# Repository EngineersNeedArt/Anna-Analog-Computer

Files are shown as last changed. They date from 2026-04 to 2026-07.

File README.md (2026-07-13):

# “Anna” Analog Computer

***Anna*** is an ecosystem of analog computing modules. The modules (each about the size of a matchbook) make use of a hobbyist breadboard and USB power that combine to make something like an analog computer trainer.

<p align="center">
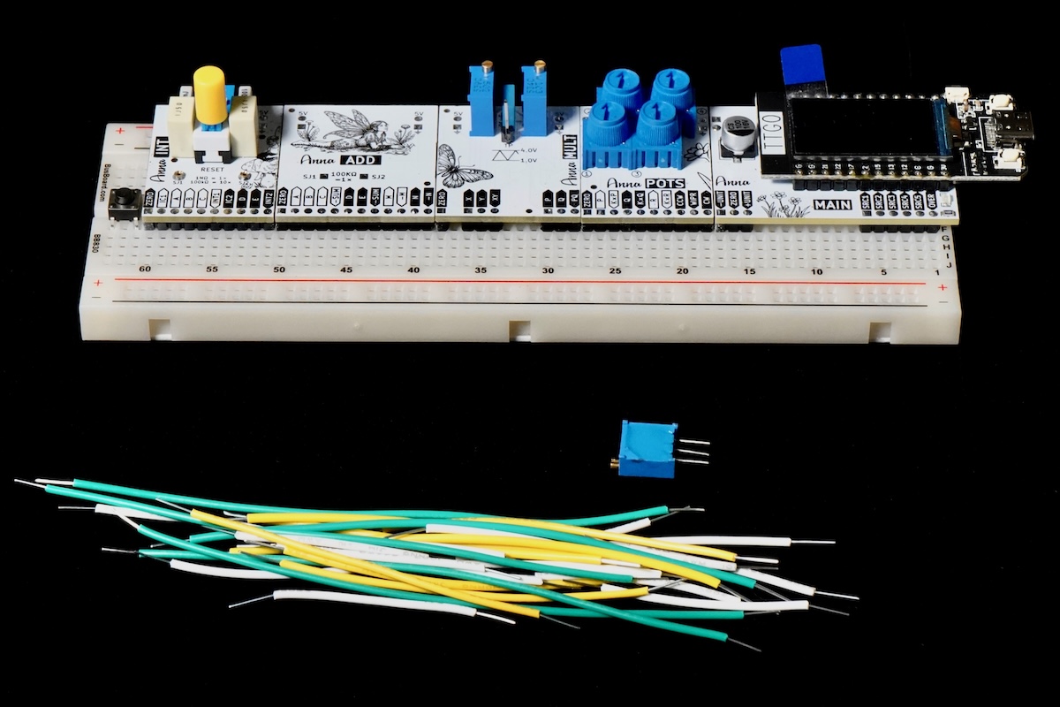
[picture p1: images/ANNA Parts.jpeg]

</p>

### Breadboard

An electronics breadboard is an integral part of ***Anna***. The breadboard allows ***Anna*** to be easily modular, expandable. It provides a power bus (the top two power rails of the breadboard) and it is acts as the “patch bay” that allows you to connect inputs and outputs between the various analog operators.

### Power

The modules comprising ***Anna*** all run on (nominally 5V) USB power. All modules but **MAIN** assume that the top two power rails of the breadboard supply this USB power. The top rail (row) of the breadboard is assumed to be +5V and the rail (row) below is assumed to be ground (GND).

While these power rails operate the electronics for each module, these rails are not to be used for the analog *programming*. There are instead three reference voltages used in the analog computing domain. These are:
- **+UNIT**, nominally 4.00V. Representing the largest machine value (+1 if you like).
- **ZERO**, nominally 2.50V. Representing the machine value zero (0).
- **-UNIT**, nominally 1.00V. Representing the smallest machine value (-1 if you like).
Needless to say, this makes the voltage window for representing values in ***Anna*** a very narrow 3 volts. Perhaps this is a good time to remind you that it is intended to be a *hobbyist* analog computer. 

## **The Modules**

### MAIN Module

<p align="center">
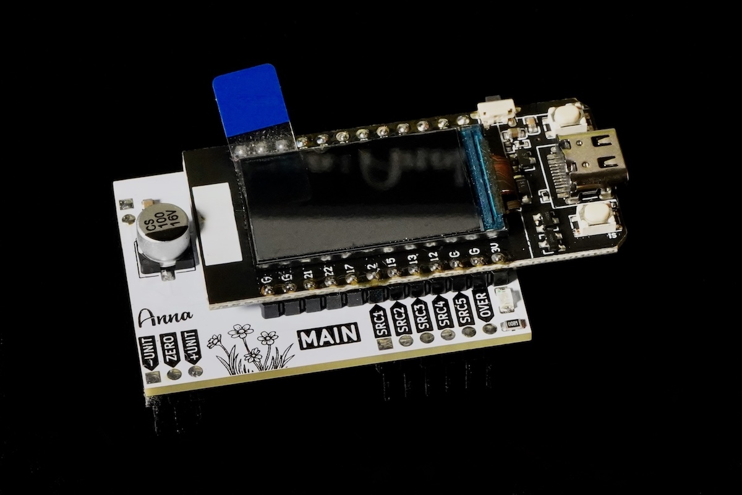
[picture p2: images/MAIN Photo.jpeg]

</p>

The **MAIN** module is required for any ***Anna*** configuration as it provides USB power to the top two rails of the breadboard. These USB power rails are what all other ***Anna*** modules depend upon to operate.
- Provides USB power to the top two power rails on the breadboard—powering all other ***Anna*** modules.
- Provides the reference voltages for **+UNIT**, **ZERO** and **-UNIT**. These are the operating voltages of the analog computer programs.
- Inputs for up to five source voltages for display on the color LCD.
- Numerous metering modes (can be cycled through using the top button on the module).
- Overload LED (and output pin) indicate when a source voltage is out of range (higher than **+UNIT** or lower than **-UNIT**).

More (esoteric) details are available in the **README** that with the **MAIN** subfolder in this repository.

### POTS Module

<p align="center">
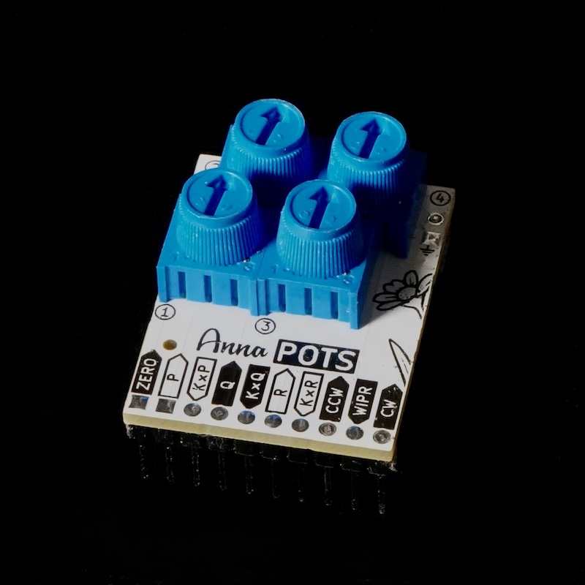
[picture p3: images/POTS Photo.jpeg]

</p>

The **POTS** module, as with the remaining modules described, is to be inserted into a breadboard such that its power pins engage in the top two power rails (top-most row: **USB 5V**, the row just below: **GND**). As described above, the **USB** power is provided by the **MAIN** board.

The **POTS** has four potentiometers—three of those are wired internally to behave as “coefficient multipliers” (in analog computer parlance). What this means, electrically, is that the low-side of the potentiometer is tied to a *machine zero* reference supplies by **MAIN**, while the user is expected to connect their input signal to the pin tied to the potʼs high-side. With the potʼs wiper connected to the output pin, the pot acts as a voltage divider—effectively attenuating the incoming voltage.

A practical use case for a coefficient multiplier is to attenuate a signal that is being used as feedback.

The 4th potentiometer on the **POTS** module is not tied to a zero-reference—the high-side of the pot is another input pin. The input pins are labeled **CCW** and **CW** referring to the rotation of the pot they correspond to. Connecting **CCW** to a **ZERO** reference makes this 4th pot behave like the other three—like a coefficient multiplier.

Like all of the modules (except for **MAIN**), **POTS** requires a **ZERO** voltage reference for the three coefficient multipliers to work correctly. The modules use op-amps employing a *virtual ground*. As indicated earlier, rather than the analog *voltages* swinging positive and negative to indicate positive and negative *values*, “zero” for ***Anna*** is 2.50V— positive values are from 2.50V to 4.00V, negative values from 2.50V down to 1.00V. So that all the modules are on the same page, they require the virtual ground connected to them from the **MAIN** module (a pin labeled **ZERO**).

(Strictly speaking, if you are using only the fourth potentiometer, you can leave off the **ZERO** reference input.)

All four pots buffer their output (using op-amps as voltage followers).

### ADD Module

<p align="center">
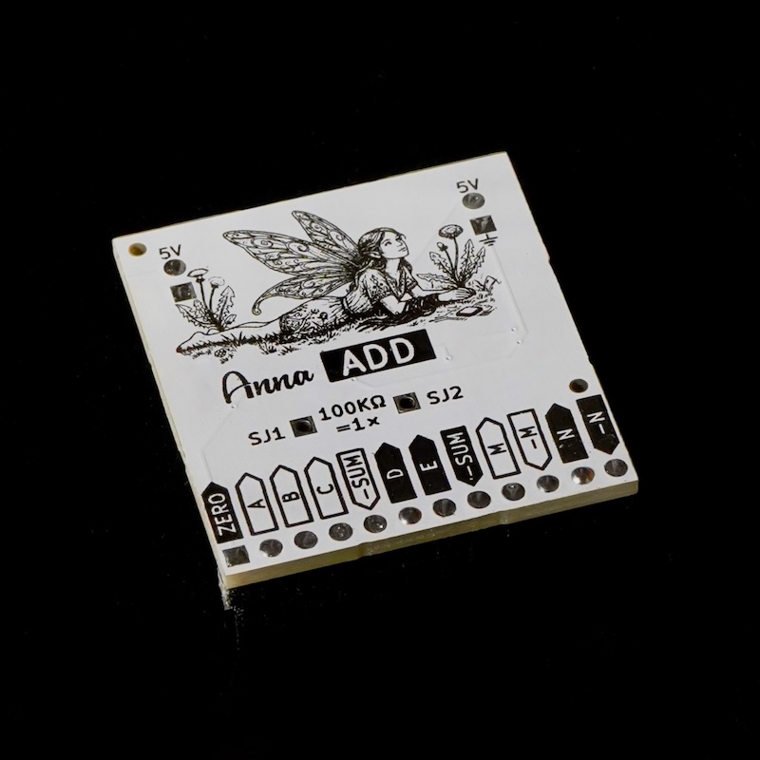
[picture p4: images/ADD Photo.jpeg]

</p>

The **ADD** module also requires **USB** power and also a **ZERO** reference voltage.

The **ADD** module has a pair of addition operators. (Or *summers*? I don't know: a “summer” is a season and an “adder” is a snake—they're both poor words). These operators take 2 or more inputs (values/voltages) and output the negative sum of those inputs.

#### Overload 

Analog computers programs have to be careful to avoid a condition referred to as **overloading**. The addition operation makes a good case for the problem. Given the voltage limitation of ***Anna*** (1V to 4V, i.e. *machine -1* to *machine +1*) what do we expect if we try to add 4V and 4V (*machine +1* plus *machine +1*)? To dive into the technical, the underlying op-amps that comprise the analog circuitry physically cannot exceed their own power rails—which we have mentioned are **5V USB** and **GND**. So a sum of 8V is already out of the question.

Instead, this condition is considered an error, called **overload**. The "programmer" must re-evaluate the program they have patched together—re-implement it to avoid overload. This might involve artificially scaling down part of an equation and then later "de-scaling" to counter.

There is no on-board overload warning on the **ADD** module. Wiring the output of any add operator to one of the voltage source inputs of **MAIN** though will catch any overloads (**MAIN** detects over/undervolts at all its inputs).

Also, going too negative (below 1V in the case of ***Anna***) is oddly also called an *overload*.

#### Inversion

You may notice that the add operators return the *inverted* sum of the inputs. That is, if you input the values for 0.2 and 0.4, the sum operator will return not 0.6 but -0.6. There is an underlying (op-amp related) reason for this. When the result of adding is needed to act as negative feedback in an equation you are modeling, this inversion is a happy accident. At times though when you need the non-inverted sum, you will have to wire the output of a summer to an inverter operator.

Any add operator with a single input will return that input value inverted as output. But since inverting is a common operation, the **ADD** module contains a pair of dedicated inverter operators. (A dedicated inverter of course needs less pins and so conserves breadboard real-estate).

### MULT Module

<p align="center">
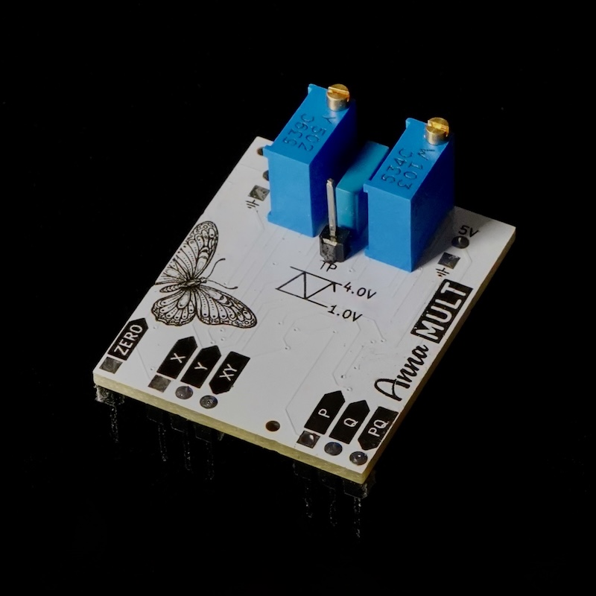
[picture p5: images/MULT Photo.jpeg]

</p>

The **MULT** module has a pair of multipliers. It performs multiplication using a PWM circuit (described in more detail in the **MULT** ReadMe.md). It requires **USB** power and a **ZERO** reference voltage.

The multiplier and multiplicand are assumed to be within *machine range* and are treated as values between 1.0 and -1.0. As such, the product will also always be within *machine range* (between 1.0 and -1.0). Consequently, the operator should not overload. (If the product ever overloads it is from an input that was already overloaded.)

A test point and two trim pots are there to allow the multiplier to be calibrated. (This requires an oscilloscope in order to adjust a triangle wave to run between 1.00 and 4.00 Volts.) After calibrating a **MULT** module, I measured it with 49 sample voltages (combinations of 7 voltages for **X** and 7 for **Y**) and measured the product. Plotting the results vs. the expected result I submitted the data to an LLM and was told the overall accuracy to be about 2.3% RMS full scale (I am lazy beyond some threshold). In general, expect some error from the **MULT** module.

### INT Module

<p align="center">
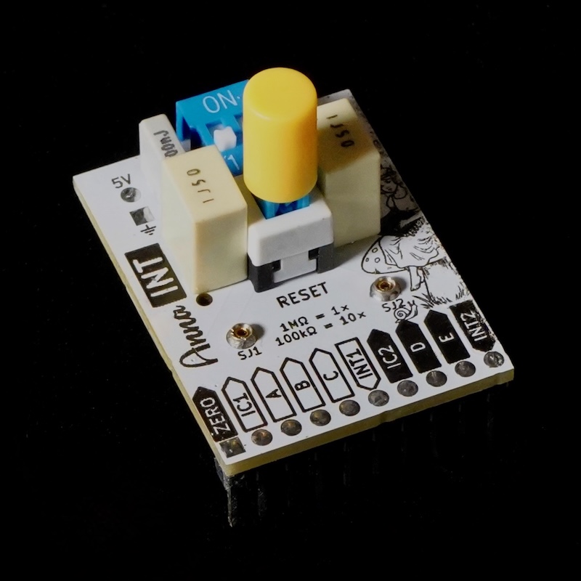
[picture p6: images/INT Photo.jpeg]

</p>

The **INT** module may be the most important one. I have read that integration was in fact the reason for early analog computing at all.

**INT** combines a pair of integrators in a single module. A single **Reset** button, when held for a short period, sets both integrators to their initial conditions (initial voltages). The “IC” of each integrator is established from the user having connected a voltage to its **IC** pin.

Integrators output a voltage—initially they are expected to be Reset and so output their IC voltage. Inputs to each integrator though can cause the output voltage of the integrator to rise or fall—the applied voltage or value is being integrated with respect to time.

Like the **ADD** module, the integrators on the **INT** module are also inverting. In practice this means that if you supply a **positive** *machine value* to an integrator, the value it outputs will get **smaller**, not larger. The reverse is the case when a **negative** machine value is applied.

If *machine zero* (**ZERO**) is applied as in input, the output of an integrator does not change.

Integrators integrate with respect to time and there is a switch on **INT** that can toggle between a *slow* integration time constant and a *fast* one. In practice, most simulations (programs), might prefer the faster integration—such as a program that models the bounce of a mass on a spring. Another program, like a game simulating a spacecraft landing on the Moon, might want to be slowed down in order to be more easy to play.

## **Future Modules**

There are some “missing modules” that will perhaps show up over time.

### Log and Anti-log Modules

Searching through older analog computer sources, you can find circuits that take a voltage as input and then output the natural **log** of that voltage. A diode (or more typically, a transistor) is employed in the *feedback loop* of an op-amp to achieve this.

Further, a diode (transistor) employed in *series* with the input to an op-amp will give you the **anti-log** from an input voltage.

*(It might be noted that the accuracy of both circuits is (apparently) encumbered by their sensitivity to temperature.)*

If a value is first passed to the **log** circuit, the result can be divided by two with a **coefficient multiplier**—the **anti-log** of this then gives you the square root of the original value.

Or, the **log** of two values can be added with an **adder** and the **anti-log** of the sum is the equivalent of the product of the original values. (Another method of multiplication.)

### Comparator Module

For some simulations a kind of *binary switch* might be desirable. For example, a bouncing ball simulation needs to know when the ball has fallen to some position where it has encountered the floor and should reverse its velocity (it should bounce). A **comparator** module would make use of an op-amp to detect when the input has crossed some threshold and then switch its output.

### Sweep Module

Some simulations might benefit by having an input that sweeps a range of values. A circuit that outputs a triangle wave would achieve this. Having a means to change the speed (period) of the sweep would be important.

### Trigonometry Module

Sine and cosine are useful operations to include. There are no simple electrical circuits that naturally give rise to these trigonometric functions. There is a method using diodes and resistors to *shape* a function from a given input. Enough diode stages in a kind of ladder configuration with precise resistor values can output a voltage that approximate, for example, the sine of the input voltage.

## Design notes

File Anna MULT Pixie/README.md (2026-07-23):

# MULT Module

The **MULT** module has two multiplier operators. Both take a pair of values assumed to be within *machine range* (between 1.0V and 4.0V). Each outputs the product of the two inputs. The outputs (products) from the **MULT** module are not inverted as they are for the **INT** and **ADD** module. This is because the **MULT** module works very differently (as is discussed below).

### ZERO

Before going further though, like the other operator modules, *machine zero* (**ZERO**, 2.5V) is a required input. The usual way to do this is to connect a wire from the **MAIN** module's **ZERO** voltage output.

### Multiplication Operation

As stated, the two values to be multiplied are assumed to be between *-UNIT* and *+UNIT*. The multiplier operators treat this range of input values as though they represent -1.0 to +1.0. With -1.0 (*-UNIT*) being the smallest value and +1.0 (*+UNIT*) the largest value to be multiplied, it should be clear that, mathematically, the product too will always be within this range. For this reason, the **MULT** module should not ever be a source of *overflow*. (The product should only overflow if one of the multiplicands was already overflowing.)

### Circuit Operation

As stated, multiplication is done in a way very different from the op-amp based modules. Describing how it works is simplified if it is broken down in steps.

<div align="center">
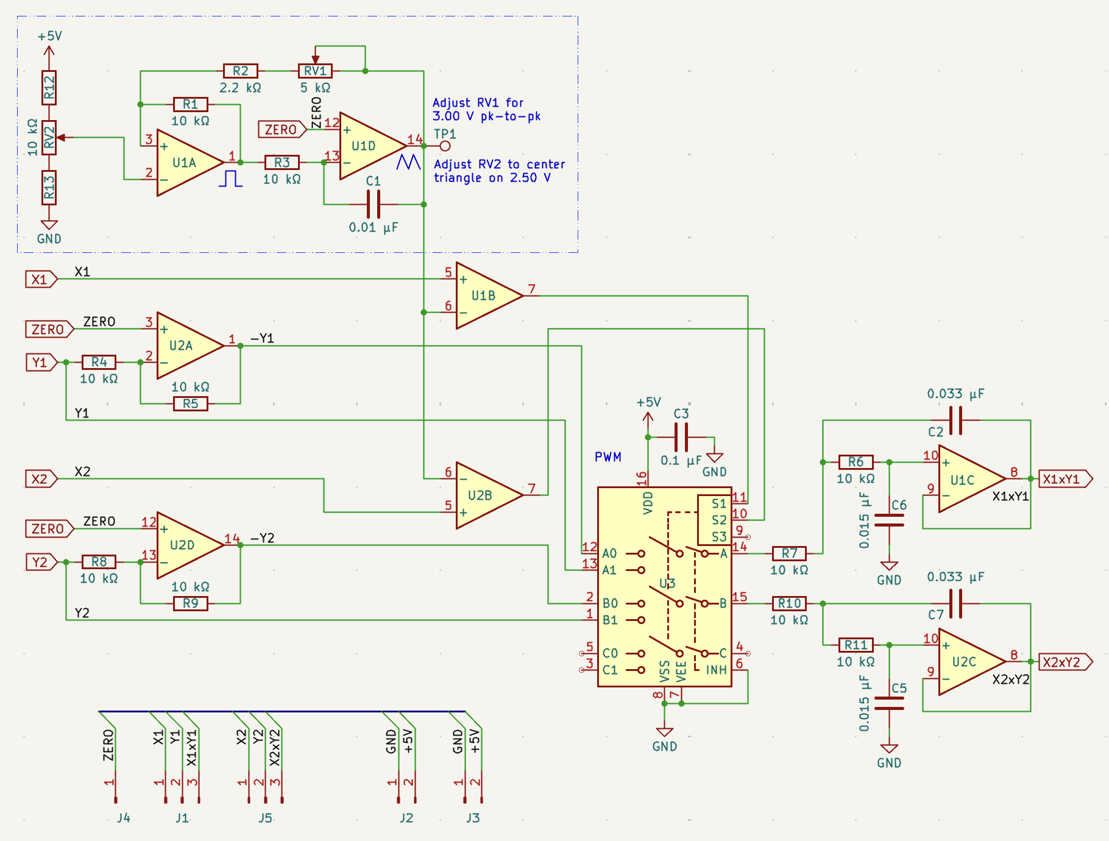
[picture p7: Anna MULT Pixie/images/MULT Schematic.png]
MULT Schematic
  
</div>

### Triangle Wave

Top-most in the schematic (above) is a circuit that outputs a triangle wave. It consists of a pair of op-amps: the first one acting as an oscillator to create an intermediary square wave, the second op-amp is wired as an integrator such that the incoming square wave causes the final triangular output.

Two trim pots are incorporated in order to adjust the triangle wave such that it peaks at 4.0V (*+UNIT*) and at it's lowest, base voltage, it is at 1.0V (-UNIT).

The purpose of the triangle wave (that oscillates at a frequency of about 4 kHz, FWIW) will be clear below.

### Comparators

Just below the triangle wave circuit (see schematic above again) is one of the multiplicand inputs labeled **X1**. It is connected to the non-inverting input of an op-amp (*U1B*). The inverting input of that op-amp if the triangle wave we described. With op-amp configured as a comparator, the output is going to be high when the non-inverting input is a greater voltage than the inverting input. For our purposes, it means that the op-amp output is high when the multiplicand (*X1*) is greater than the value of the triangle wave.

Let's stop and think about what that means. If **X1** is *machine zero* (recall, 2.5V) and the triangle wave is ramping up and down symmetrically between 1.0V (*-UNIT*) and 4.0V (*+UNIT*), then it should be the case that the output from the comparator is split 50/50 between being high and being low.

If instead **X1** is greater than *machine zero* (greater than 2.5V) then the output from **U1B** should be higher more than 50% of the time. If this sounds to you like **X1** is controlling the *duty cycle* of comparator **U1B**, pat yourself on the back.

You should note that an identical circuit to the one just described exists below on the schematic—for **X1** and **U2B**. I will only be describing the one circuit.

### Switching

Following the schematic, the pulse-width modulated (PWM) output from **U1B** goes to the rather large rectangular circuit/chip. This integrated circuit is an analog switch, and **U1B** is connected to drive one of the internal switches (*S1*). This is the "A" switch in the IC and it controls whether **A0** or **A1** are selected for output **A**.

Recall that if **X1** is *machine zero* we expect a 50% duty-cycle. This would mean that **A** would output **A0** half of the time and **A1** the other half of the time. And what then are **A0** and **A1**?

**A1** is simple, it comes directly from **Y1**, our multiplier.

**A0** is a little more complicated, it comes from an op-amp (*U2A*) acting as an inverting op-amp. In fact, **A0** is **Y1** inverted (the negative value). So if **Y1** is *+UNIT*, **U2A** will output *-UNIT*. Another example, if **Y1** is *machine zero*, the inverted value is also *machine zero*.

What does this mean if we are switching between **Y1** and inverted **Y1**? Before we answer that question, let's look at the final stage of the circuit.

### Filtering

The final stage for our multiplier operator that began with is **X1** and **Y1** is the op-amp (*U1C*) that outputs the product (**X1×1**). This final op-amp is configured as an active filter. It *smooths* the output of switch **A** to a voltage (value) that is the kind of average of the output.

Back to our early example, if we are switching between **Y1** and **-Y1** (inverted **Y1**) and spending 50% of the time at each voltage, the *average* value will be *machine zero*. Does that make sense? If **Y1** is *+UNIT* then **-Y1** will be *-UNIT* and, when averaged, will give *machine zero*.

In fact, this is what we expect mathematically: recall that 50% duty cycle was for an **X1** that was *machine zero*—and any number multiplied by zero if of course zero.

So what happens when **X1** is greater than *machine zero*? We said above that the output of our comparator would be high more often than low in that case. This will correspond to **Y1** being switched in more often than the inverted **-Y1**. And this will *average* out to a value closer to **Y1**.

In the extreme case, if **X1** is *+UNIT* (the largest value and treated as though it is numerically 1.0) then the output of the comparator should remain high and the switched output then simply **Y1**. Again, this is expected as 1.0 times any number is that number.

I'll leave it as an exercise for you to understand the operation of the circuit when **X1** is *-UNIT* or when **Y1** is *machine zero*.

## TODO

• An inverted output would be nice: **-X × Y**. This would require additional op-amps.

• There is a cap that is a touch too close to the edge of the PCB.

• Silkscreen show **X × Y** instead of **XY**. (Perhaps **X ⋅ Y**)

• Larger butterfly art.

• Possibly replace trim pots with specific resistor values found to be correct.

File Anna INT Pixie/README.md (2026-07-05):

# INT Module

The **INT** module consists of a pair of integrators. One of the integrators has three inputs and the other has two.

<div align="center">
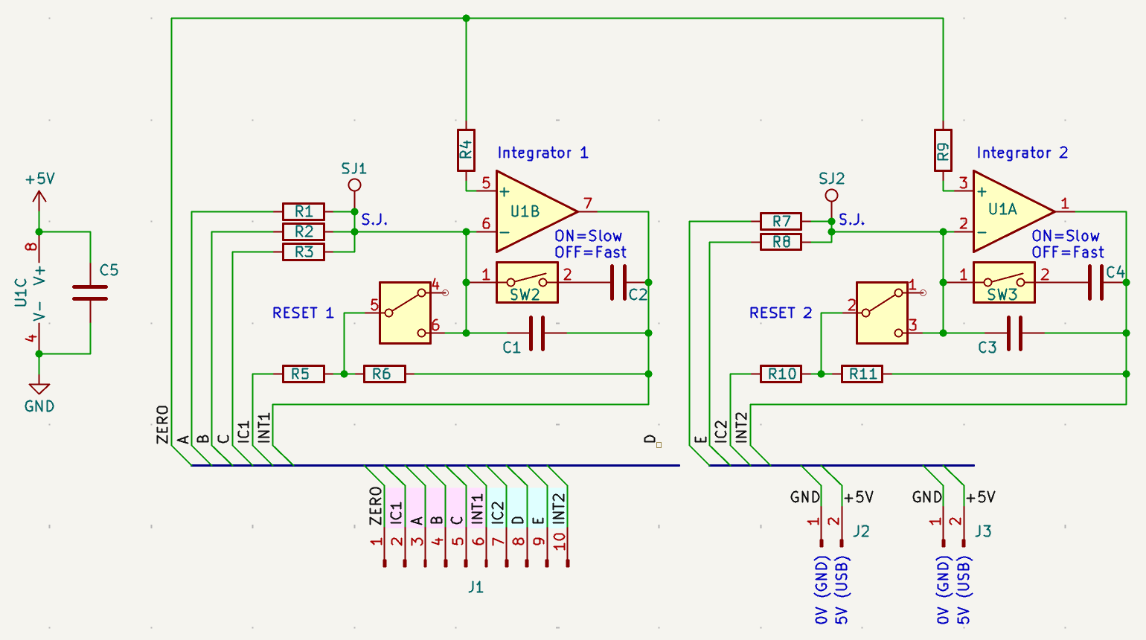
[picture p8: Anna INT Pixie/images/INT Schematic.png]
INT Schematic
  
</div>

## Zero

It will probably come as no surprise that the **INT** module also expects a *machine zero* reference as input. Like the **ADD** module, *machine zero* (ZERO) is used as a *virtual ground* on the non-inverting input of the op-amps.

Like the **ADD** module, this is why the output of the integrator is inverted. Since input values/voltages are connected to the inverting input, they have an inverse effect on the output of the integrator. A positive value (voltage above 2.5V) will in fact cause the integrator output to decrease while a negative value (a voltage below 2.5V) causes the integrator output to become more positive.

## Reset

Each integrator has an *initial condition* (IC) input. This is a value/voltage that the user supplies to be the starting value (output) for each integrator. A single momentary switch, when held down for a short time, resets both integrators to this initial condition.

## Integration Speed

Unlike the other **“Anna”** modules, the integrators have a kind of *speed* associated with them—the speed of integration. The value of the input resistors and the size of the capacitor in the op-amp feedback circuits contribute to determine the speed of integration.

It was found that some simulations, like *Lunar Lander* for example, preferred a slower integration time—to allow the player to react to their descending spacecraft. Other simulations, such as a mass on a spring, felt more realistic with a faster integrator.

To address either scenario, the **INT** module has a separate switch for each integrator that allows for toggling in or out of the op-amp feedback an additional capacitor. With just the one capacitor in the feedback path, an integrator will run faster for simulations like the *spring and mass*. Switching in a second capacitor in parallel slows the integration down by roughly an order of magnitude—making a game like *Lunar Lander* playable.

## Summing Junctions

Like the **ADD** module, the **INT** module also makes accessible the “summing junction” for each integrator. The summing junction is where all the inputs tie together and connect to the inverting input of an op-amp.

If a user wishes for an additional input, a 1 MΩ input resistor can be connected in series with the input and one of the summing junctions on the **INT** module.

Alternatively, if a smaller resistor value is used as an input resistor, such as a 100 kΩ resistor, that input will move the integrator 10x (ten times) as fast. It is possible then to have a much quicker integrator (or much slower) by using input resistors other than 1 MΩ.

## TODO

• Claude suggested adding a "pull to ZERO" resistor on every input. (Perhaps using 10MΩ resistors.)

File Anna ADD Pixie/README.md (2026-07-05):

# ADD Module

Like the other **“Anna”** modules, the **ADD** module is powered by 5V (nominal) USB voltages. Pins along the top edge are placed and spaced to draw USB power from the top two *power rails* of a standard electronics breadboard. The circuitry of the **ADD** module consists of operational amplifiers (op-amps) to perform the adding of voltages—the USB power limits the output of the **ADD** module to within the 0V to 5V range.

Also like the most of the other **“Anna”** modules, the **ADD** module requires a “zero” reference of 2.50V. An input pin in the lower-left corner of the PCB is provided for this reference voltage to be supplied. The 2.50V is supplied to the non-inverting input of the op-amps that perform the operations and therefore acts as a *virtual ground*.

## Overload

Currently there is no **overload** detection on the **ADD** module itself. If the result of operating on an input voltage results in a voltage outside of the range of **“Anna's”** defined machine range of 1.0V and 4.0V, it is simply presented as is. The **MAIN** module has overload detection on all five of its source voltage inputs and is typically where you will detect an overload.

<div align="center">
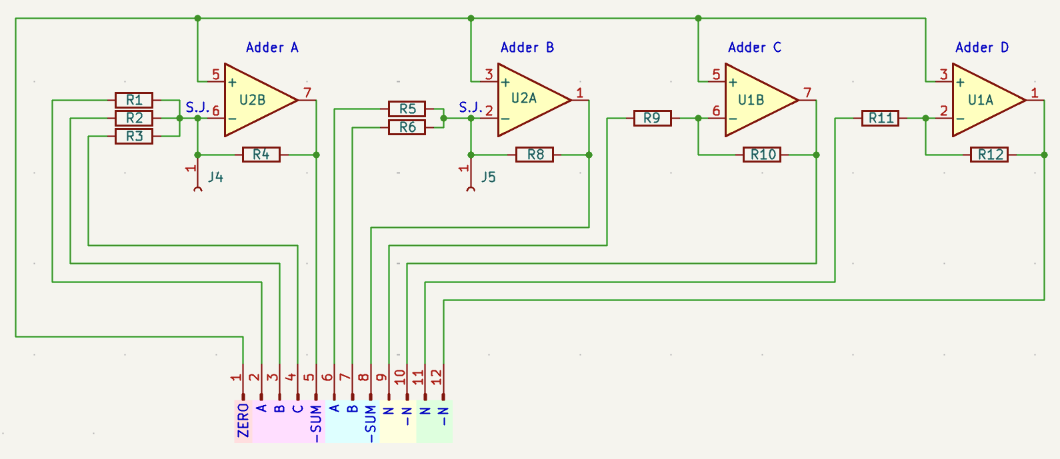
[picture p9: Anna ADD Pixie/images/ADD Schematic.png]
ADD Schematic
  
</div>

## Summing Junction

The schematic (above) shows four op-amps, their non-inverting inputs tied to virtual ground (“zero”, 2.50V). Adder **A** has three inputs and adder **B** has two—these are connected to the inverting inputs of the corresponding op-amps. In both cases, where the inputs tie together (known as the *summing junction*) and test-point is provided such that a user can join additional inputs if desired.

Input resistors on the **ADD** module are 100 kΩ. If similar resistor values are used for additional inputs at the summing junction, the extra inputs will be added normally. However, an input resistor value 10x (ten times) 100 kΩ (1 MΩ) will “weigh” the input by 0.1x (one-tenth). An input resistor that is 0.1x of 100 kΩ (10 kΩ) has the opposite weighting effect—the input is treated as 10x (ten times).

## Inverted Output

By connecting the inputs to be added to the inverting input of the op-amp, the result will also be inverted—the inverted sum of the input voltages. This is why the **ADD** module returns the negative sum (-SUM). I am not expert enough in electronics to understand fully why we use the inverting input for the summing junction.

From an LLM (since this is where it gets fuzzy for me), “The summing junction works because each voltage input behaves independently—seeing only its source voltage across its input resistor, with virtual ground on the other end. That virtual ground exists at the inverting input because the op-ampʼs feedback loop continuously drives it to match the actual ground connected to the non-inverting input. You canʼt simply swap the summing junction to the non-inverting input because virtual ground only exists at the inverting input—without it, the inputs interact with each other and the clean superposition breaks down.”

## Inverters

When analog computing, it turns out that inverting a value is common enough that the **ADD** module dedicates two op-amps just to take an input and return the inverted output. While any **ADD** operator will do the same with a single input, the dedicated inverters save on “breadboard real-estate” (number of pins).

## TODO

• Claude suggested adding a "pull to ZERO" resistor on every input. (1MΩ to 10MΩ)

• S.J. (summing junction) hole is the wrong size.

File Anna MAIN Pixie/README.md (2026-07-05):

# MAIN Module

## Software

**MAIN** features a *daughter board* consisting of an ESP32 Dev Board that includes an LCD display and two soldered-on pushbuttons. Software written for **MAIN** makes use of the display and buttons.

## Metering Modes

The bottom-right button, the one closest to the user, Iʼll call the *mode button*, was chosen to cycle through **MAIN**s various metering modes. The other button, Iʼll call the *options button*, often cycles through various options for the selected metering mode.

### Vertical Meters

<div align="center">
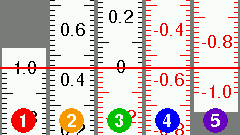
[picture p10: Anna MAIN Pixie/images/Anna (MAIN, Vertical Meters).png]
Vertical Meters screenshot

</div>

The default metering mode consists of five moveable, vertical meters and a fixed red index line. They are labeled 1 through 5 and correspond to the inputs on **MAIN**, **SRC1** through **SRC5**. The *options button* allows you to toggle the number of inputs displayed from the 5 down to just 1. Overload is represented by the labels flashing.

### Sweep Meters

<div align="center">
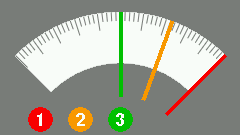
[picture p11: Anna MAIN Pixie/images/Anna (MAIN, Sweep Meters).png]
Sweep Meters screenshot

</div>

Looking like traditional analog panel meters, the magic of digital emulation means that 5 needles can share the same meter. They are labeled 1 through 5, color coded, and correspond to the inputs on **MAIN**, **SRC1** through **SRC5**. The *options button* allows you to toggle the number of inputs displayed from the 5 down to just 1. Overload is represented by the labels flashing.

***(NOTE: in the screenshot only 3 inputs are enabled.)***

### Strip Chart

<div align="center">
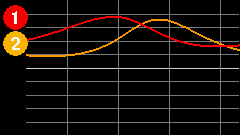
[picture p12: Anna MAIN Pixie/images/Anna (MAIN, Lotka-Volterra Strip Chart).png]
Strip Chart screenshot

</div>

The Strip Chart is a moving metering mode that can display all 5 source inputs with roughly 4 seconds of history visible. The vertical rules that scroll by mark off 1 second intervals. The *options button*  allows you to toggle the number of inputs displayed. *Overload* is represented by the labels flashing.

***(NOTE: in the screenshot only 2 inputs are enabled.)***

### XY Scope

<div align="center">
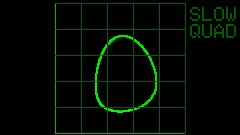
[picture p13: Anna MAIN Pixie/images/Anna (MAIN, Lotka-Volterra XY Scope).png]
XY Scope screenshot

</div>

The XY Scope is patterned after an oscilloscope. It makes use of **SRC1** to control the X-position of a dot and **SRC2** to control the Y-position. The *options button* toggles between displaying the whole *machine value* range to displaying just Quadrant I (the positive *machine values*). The *options button* also toggles between two *fade speeds* for the phosphor trace: slow and fast.

### Spring + Mass

<div align="center">
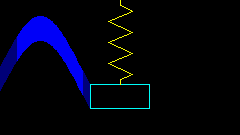
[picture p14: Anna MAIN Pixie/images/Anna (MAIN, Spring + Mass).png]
Spring + Mass screenshot

</div>

Spring + Mass is a special demonstration metering mode. It represents a mass on a spring. The vertical position of the mass is controlled solely by the voltage at **SRC1**. The *options button* does nothing.

The mass leaves a “trail” sort of like the Strip Chart. A color change indicates 1-second intervals.

### Lunar Lander

<div align="center">
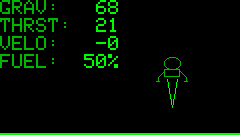
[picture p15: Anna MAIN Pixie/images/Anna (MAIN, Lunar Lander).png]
Lunar Lander screenshot

</div>

Lunar Lander is another special metering mode that is a game. It expects a gravitational constant to be presented at **SRC1**, the intermittent thrust to be connected to **SRC2**, the spacecraft velocity to be connected to **SRC3** and the spacecraft elevation/altitude to be connected to **SRC4**. An optional *fuel level* voltage can be connected to **SRC5**.

The above connections presume that the user has wired up the lunar lander program on the analog computer—supplied the above voltages as described.

Starting the game is done by simply resetting the integrators that dictate velocity (reset to **ZERO**), altitude (reset to **+UNIT**) and, if the fuel level integrator is wired up, resetting the fuel level to **+UNIT**. Doing so put the spacecraft at the top of the display, with no vertical velocity, and optionally with a full tank of fuel.

As the spacecraft descends, the software monitors the spacecraft altitude (**SRC4**) to determine touch-down. When the spacecraft altitude passes the touch-down threshold, velocity (**SRC3**) is evaluated by the software to determine if the landing was safe. The **MAIN** display will indicate a safe landing or a crash.

If the optional fuel level (**SRC5**) ever drops to an empty tank, the game will indicate a crash landing.

### Raw Values

<div align="center">
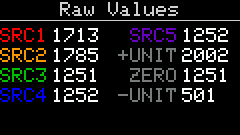
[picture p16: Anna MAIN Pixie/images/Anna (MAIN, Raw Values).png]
Raw Values screenshot

</div>

Initially kind of a debug mode, it displays the raw values of the inputs coming off the ADCs (Analog to Digital chips). In addition to **SRC1** through **SRC5** though, it also shows the measured values for **+UNIT**, **ZERO** and **-UNIT**.

When a source input is indicated as Overloading, it is because it is outside the range of the measured **+UNIT** and **-UNIT**. It is indicated in this mode when the inputʼs label is rendered white. **+UNIT**, **ZERO** and **-UNIT**, by definition, can never be “overloading”.

When a source input is displayed on the LCD, as a reading on a meter for example, it is arrived at by finding where the source input value is proportionally between the reference values (voltages). If, for example, the value is greater than **ZERO**, itʼs relative value is determined by scaling it proportionally between the measured **ZERO** and **+UNIT**.

## Hardware

<div align="center">
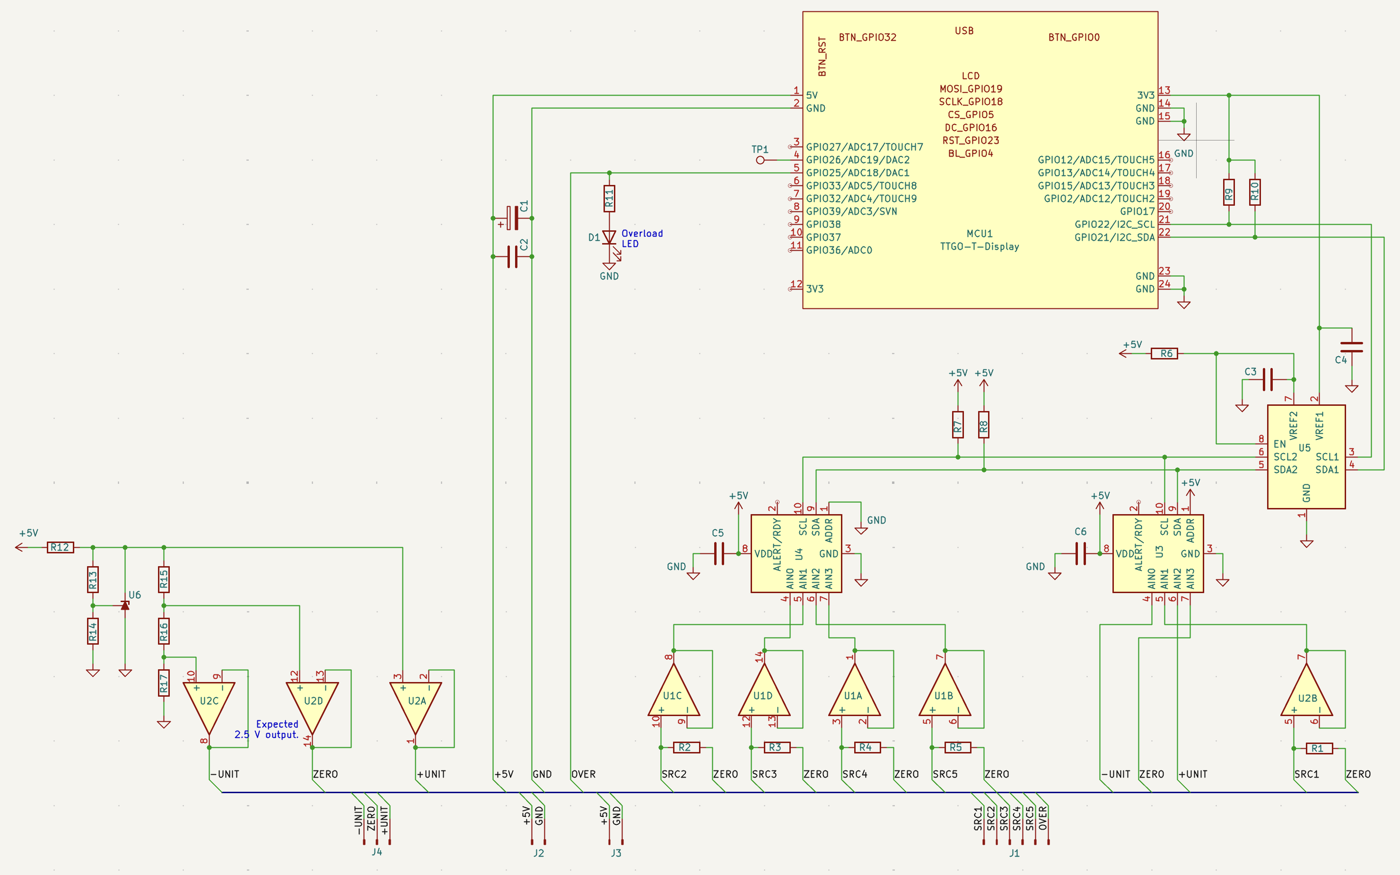
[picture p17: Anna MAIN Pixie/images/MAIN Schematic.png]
MAIN Schematic

</div>

The ESP32 dev board (LILYGO T-Display) dominates the schematic with the large yellow box in the upper right. It has the USB-C connection from which the entire **“Anna”** ecosystem derives USB power. A pair of capacitors serve to smooth the current on those power rails.

### Buffering

Across the bottom are eight op-amps involved in buffering (wired as voltage followers). Three are used to buffer the outputs of the machine values/voltages (1.0V, 2.5V and 4.0V)—in this way the voltages are protected from being loaded down by the analog circuitry.

The other five op-amps are used to buffer the five source-voltage inputs to **MAIN**. 

### ADC

Just above the op-amps are a pair of ADC chips (analog-to-digital). Each chip has four channels for a total of eight inputs. Three of these are dedicated to converting the machine values/voltages (1.0V, 2.5V and 4.0V) to digital form. The other five are, unsurprisingly, used to convert the source-voltage inputs (**SRC1** through **SRC5**) to digital form.

The ESP32 reads the 8 digital values over I2C.

*Note: the ESP32 works on 3.3V and can be damaged by the 5V that **“Anna”** uses. The ADC chips are running from 5V and can therefore directly interface **“Anna's”** 5V inputs. To interface between the ADC chips and the ESP32, a dedicated chip handles level-shifting the I2C connection.*

When, for example, the ESP32 is to display a source-voltage input as a needle on a meter, it can use the three digital machine values to find a proportional position to move the needle to.

Further, if any digital source-voltage input exceeds the digital positive machine unit value or is less than the digital negative machine unit value, it is flagged as **overloading**.

### Voltage Sources

A last point to call out is the small component on the far-left (U5). It takes the voltage from USB and provides the stable 4.0V that **“Anna”** uses for positive machine value. The other machine values (zero and negative unit), are pared from the 4.0V using carefully selected resistor values arranged as voltage dividers.

## TODO

• The holes that receive the ESP32 Dev Board on the PCB are still a little tight. Open them up to the next drill size.

• I'm not a fan of the super-tiny SMD resistors. Perhaps move up to the next SMD resistor size.

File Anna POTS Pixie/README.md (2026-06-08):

# POTS Module

Four op-amps buffer the outputs from the four potentiometers of the **POTS** module. In this way, circuits connected to the output to not load the potentiometer and drag down itʼs voltage.

<div align="center">
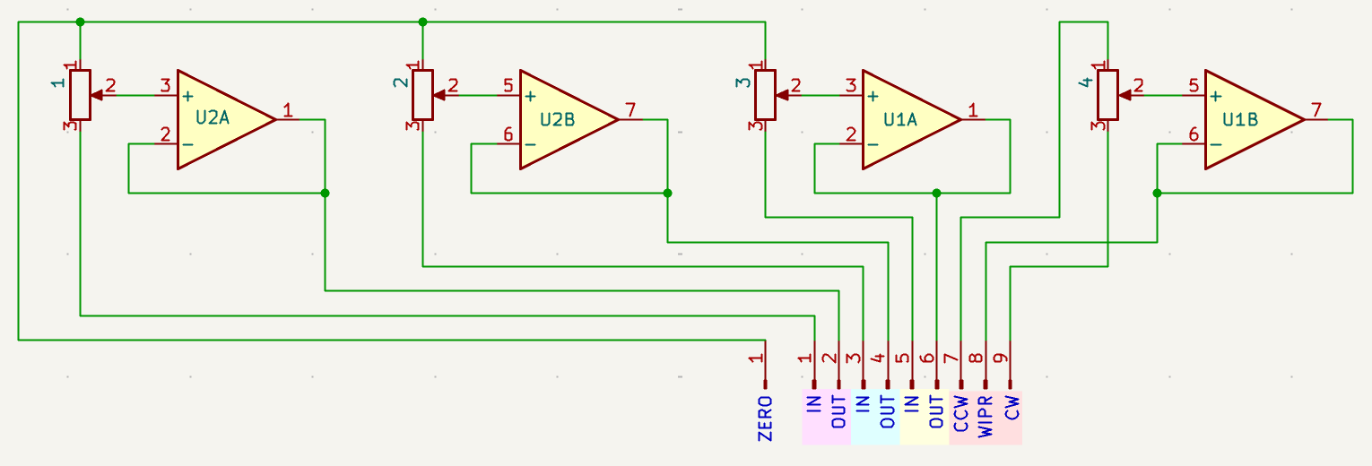
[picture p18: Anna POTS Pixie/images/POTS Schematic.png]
POTS Schematic
  
</div>

## Coefficient Multipliers

Again, as with the other modules (excluding **MAIN**), we have a **ZERO** input that is expected to be the *Zero* machine value (2.5V provided by **MAIN**). In the case of **POTS** though it is used merely as the CCW (counter-clockwise) input on each of three potentiometers. In this way, the potentiometers behave as (to use analog computing terminology) *coefficient multipliers*. That is, given an input value/voltage on the other end of the pot, the wiper of the pot will present (output) a value/voltage between input and *machine zero*. In this way it is *attenuating* the input (multiplying by a factor between 0.0 and 1.0).

A common use-case for a coefficient multiplier in analog computing might be to feedback some portion of a value, perhaps from an integrator, back into itʼs input. For example, if an integrator is representing velocity, a portion of that velocity might be used to represent the friction impeding the velocity. A coefficient multiplier allows you to dial in a coefficient of friction.

Another common use case is to present a value/voltage less than the *positive machine unit* or greater than the *negative machine unit*.

## Open-Ended Potentiometer

The fourth potentiometer is not tied to *machine zero*—both ends of the potentiometer are user inputs. This is more open-ended potentiometer—allowing the user to connect any value/voltage pair to the inputs and use the pot knob to select an output value/voltage anywhere in between. If *positive machine unit* is connected as one input and *negative machine unit* connected to the other, the output (wiper) can represent all machine values for **“Anna”**.

Further, if you should connect *machine zero* to the CCW (counter-clockwise) input, you have a fourth coefficient multiplier.

## Power

Not shown in the schematic, the op-amps, again, are powered from the (nominal) 5V USB power in the same way the rest of **“Annaʼs”** modules are.

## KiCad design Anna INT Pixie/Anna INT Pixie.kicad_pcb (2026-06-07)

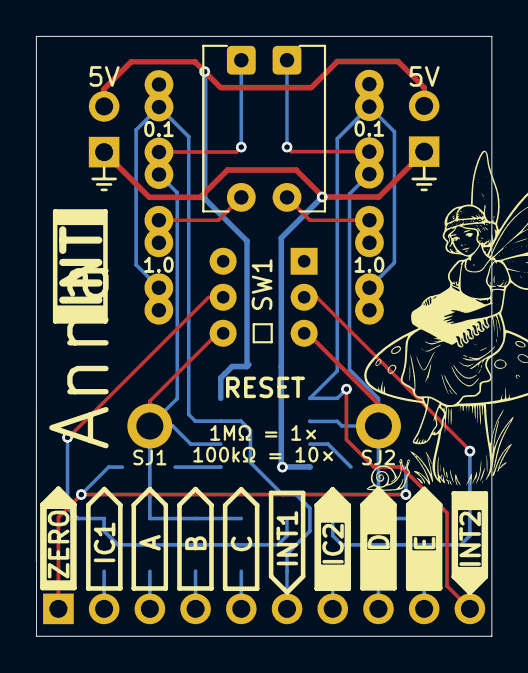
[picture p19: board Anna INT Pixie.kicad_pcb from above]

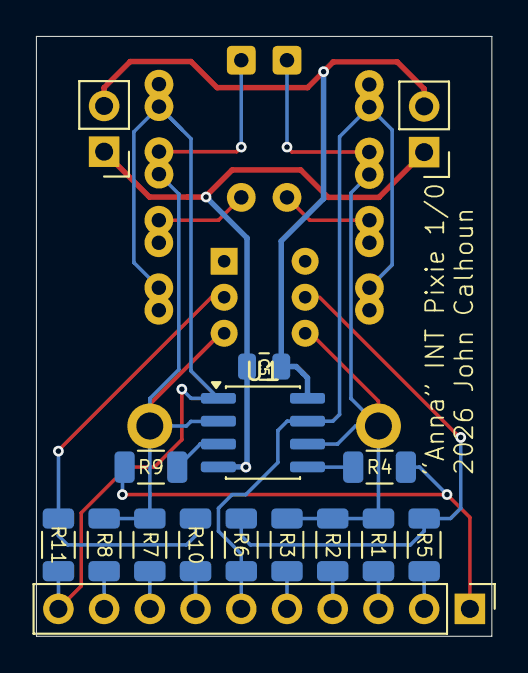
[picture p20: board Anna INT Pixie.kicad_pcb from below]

Board: 2 copper layers, 25.3 x 33.3 mm, 25 parts (16 on the bottom side), 19 nets.

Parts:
0.1, 0.1#2: 0.1 µF; C_Rect_L7.0mm_W3.5mm_P2.50mm_P5.00mm
1.0, 1.0#2: 1 µF; C_Rect_L7.0mm_W3.5mm_P2.50mm_P5.00mm
C5: 0.1 µF; C_0805_2012Metric
J1: Conn_01x10_Pin; PinHeader_1x10_P2.54mm_Vertical
J2, J3: Conn_01x02_Pin; PinHeader_1x02_P2.54mm_Vertical
R1, R2, R3, R4, R7, R8, R9: 1 MΩ; R_1206_3216Metric
R5, R6, R10, R11: 100 kΩ; R_1206_3216Metric
SJ1, SJ2: TestPoint; TestPoint_THTPad_2.0x2.0mm_Drill1.0mm
SW1: SW_DPDT_x2; SW_Push_2P2T_Momentary_Anna_INT
SW2, SW3: SW_DIP_x01; SW_DIP_SPSTx01_Piano_10.8x4.1mm_W7.62mm_P2.54mm
U1: MCP6002-xMC; SOIC-8_3.9x4.9mm_P1.27mm

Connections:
+5V: C5.1, J2.2, J3.2, U1.8 (V+)
/A: J1.3, R1.2
/B: J1.4, R2.2
/C: J1.5, R3.2
/E: J1.9, R8.2
/IC1: J1.2, R5.2
/IC2: J1.7, R10.2
/INT1: 0.1.2, 1.0.2, J1.6, R6.1, U1.7
/INT2: 0.1#2.2, 1.0#2.2, J1.10, R11.1, U1.1
/ZERO: J1.1, R4.1, R9.1
GND: C5.2, J2.1, J3.1, U1.4 (V-)
unnamed: 1.0.1, SW2.2
unnamed: 1.0#2.1, SW3.2
unnamed: R10.1, R11.2, SW1.2 (B)
unnamed: 0.1#2.1, R7.1, R8.1, SJ2.1 (1_1), SW1.3 (C), SW3.1, U1.2 (-)
unnamed: R5.1, R6.2, SW1.5 (B)
unnamed: 0.1.1, R1.1, R2.1, R3.1, SJ1.1 (1_1), SW1.6 (C), SW2.1, U1.6 (-)
unnamed: R9.2, U1.3 (+)
unnamed: R4.2, U1.5 (+)

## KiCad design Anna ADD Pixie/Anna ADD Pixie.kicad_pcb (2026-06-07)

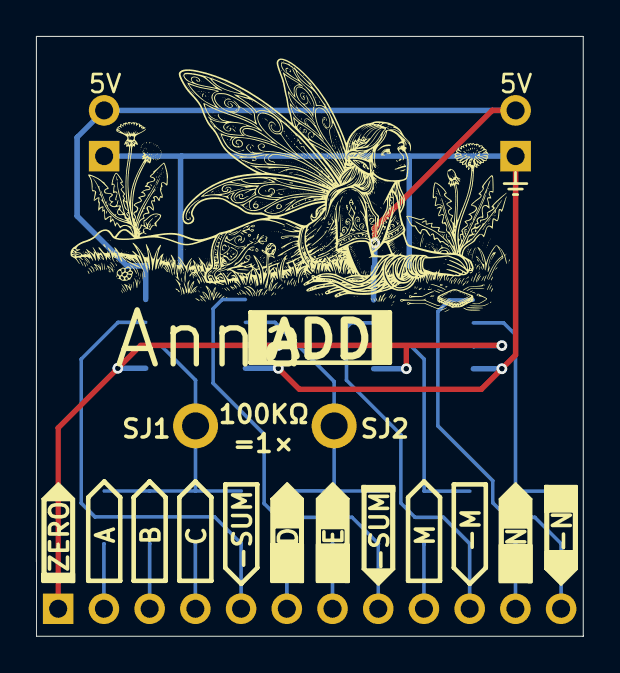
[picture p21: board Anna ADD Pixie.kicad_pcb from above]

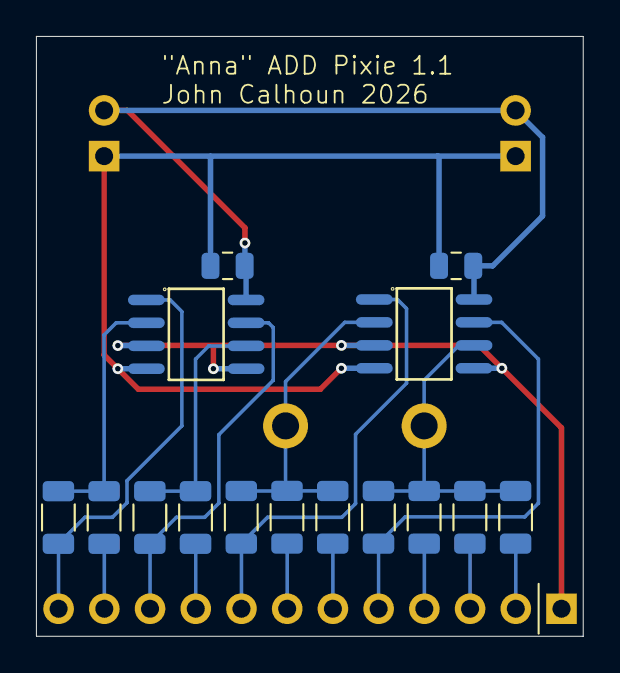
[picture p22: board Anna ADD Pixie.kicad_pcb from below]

Board: 2 copper layers, 30.4 x 33.3 mm, 20 parts (18 on the bottom side), 18 nets.

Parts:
C4, C5: 0.1 µF; C_0805_2012Metric
J1: Conn_01x13_Pin; PinHeader_1x12_P2.54mm_Vertical
J2, J3: Conn_01x02_Pin; PinHeader_1x02_P2.54mm_Vertical
J4, J5: Conn_01x01_Socket; PinSocket_1x01_P2.54mm_Vertical
R1, R2, R3, R4, R5, R6, R8, R9, R10, R11, R12: 100 kΩ; R_1206_3216Metric
U1, U2: MCP6002-xMC; SOIC-8_L4.9-W3.9-P1.27-LS6.0-BL

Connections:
GND: C4.2, C5.2, J2.1, J3.1, U1.4 (V-), U2.4 (V-)
unnamed: J1.1, U1.3 (+), U1.5 (+), U2.3 (+), U2.5 (+)
unnamed: J1.2, R1.2
unnamed: J1.3, R2.2
unnamed: J1.4, R3.2
unnamed: J1.5, R4.2, U2.7
unnamed: J1.6, R5.2
unnamed: J1.7, R6.2
unnamed: J1.8, R8.2, U2.1
unnamed: J1.9, R9.2
unnamed: J1.10, R10.1, U1.7
unnamed: J1.11, R11.2
unnamed: J1.12, R12.1, U1.1
unnamed: C4.1, C5.1, J2.2, J3.2, U1.8 (V+), U2.8 (V+)
unnamed: J4.1, R1.1, R2.1, R3.1, R4.1, U2.6 (-)
unnamed: J5.1, R5.1, R6.1, R8.1, U2.2 (-)
unnamed: R11.1, R12.2, U1.2 (-)
unnamed: R9.1, R10.2, U1.6 (-)

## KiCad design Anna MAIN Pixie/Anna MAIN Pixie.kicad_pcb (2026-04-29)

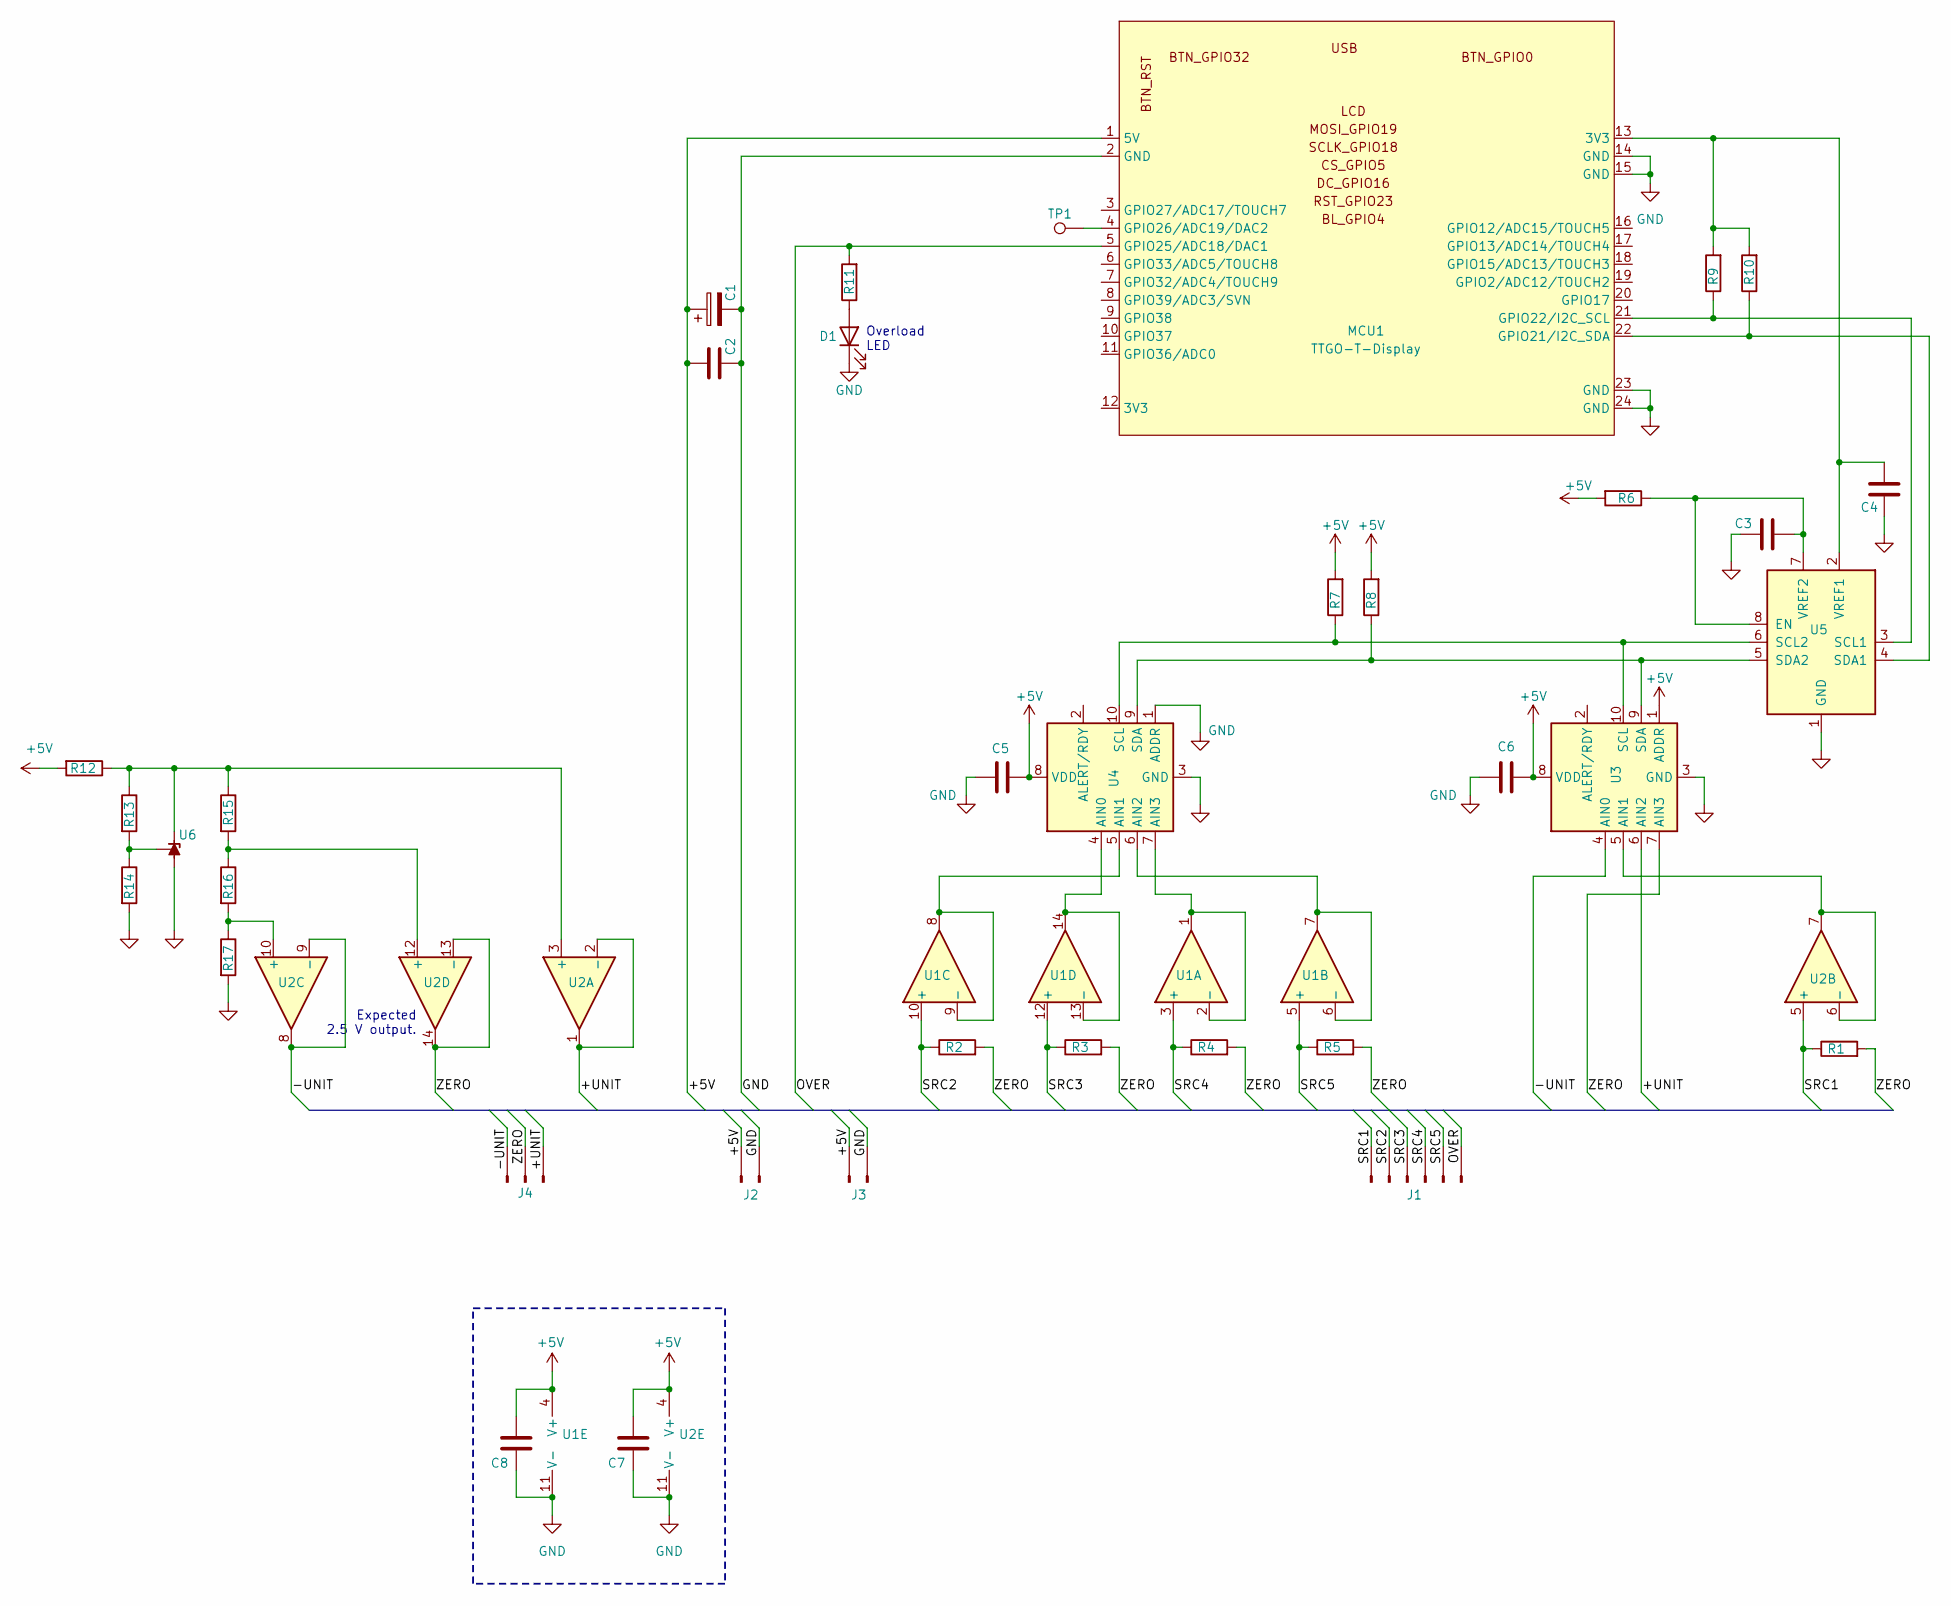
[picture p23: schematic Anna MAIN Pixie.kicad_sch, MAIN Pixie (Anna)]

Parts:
C1: 100 µF; CP_Elec_6.3x5.4; LCSC C97805
C2, C3, C4, C5, C6, C7, C8: 0.1 µF; C_0805_2012Metric; LCSC C49678
D1: LED; LED_1206_3216Metric; LCSC C49018
J1: Conn_01x06_Pin; PinHeader_1x06_P2.54mm_Vertical
J2, J3: Conn_01x02_Pin; PinHeader_1x02_P2.54mm_Vertical
J4: Conn_01x03_Pin; PinHeader_1x03_P2.54mm_Vertical
MCU1: TTGO-T-Display
R1, R2, R3, R4, R5: 100 kΩ; R_0603_1608Metric; LCSC C25803
R6: 330 kΩ; R_0603_1608Metric; LCSC C23137
R7, R8, R9, R10: 4.7 kΩ; R_0603_1608Metric; LCSC C23162
R11: 680 Ω; R_0805_2012Metric; LCSC C17798
R12: 47 Ω; R_0603_1608Metric; LCSC C114623
R13: 6.04 kΩ (0.1%); R_0603_1608Metric; LCSC C728595
R14, R17: 10 kΩ (0.1%); R_0603_1608Metric; LCSC C95204
R15, R16: 15 kΩ (0.1%); R_0603_1608Metric; LCSC C326733
TP1: TestPoint; TestPoint_THTPad_1.5x1.5mm_Drill0.7mm
U1, U2: MCP6004; SOIC-14_L8.7-W3.9-P1.27-LS6.0-BL; LCSC C7378
U3, U4: ADS1015; VSSOP-10_3x3mm_P0.5mm; LCSC C701605
U5: PCA9306DCUT; VSSOP-8_2.3x2mm_P0.5mm; LCSC C33196
U6: TL431DBZ; SOT-23-3; LCSC C350683

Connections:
+5V: C1.1, C2.1, C5.2, C6.2, C7.2, C8.2, J2.1, J3.1, MCU1.1 (5V), R6.2, R7.2, R8.2, R12.2, U1.4 (V+), U2.4 (V+), U3.1 (ADDR), U3.8 (VDD), U4.8 (VDD)
/+UNIT: J4.3, U2.1, U2.2 (-), U3.6 (AIN2)
/-UNIT: J4.1, U2.8, U2.9 (-), U3.4 (AIN0)
/OVER: J1.6, MCU1.5 (GPIO25/ADC18/DAC1), R11.2
/SRC1: J1.1, R1.1, U2.5 (+)
/SRC2: J1.2, R2.1, U1.10 (+)
/SRC3: J1.3, R3.1, U1.12 (+)
/SRC4: J1.4, R4.1, U1.3 (+)
/SRC5: J1.5, R5.1, U1.5 (+)
/ZERO: J4.2, R1.2, R2.2, R3.2, R4.2, R5.2, U2.13 (-), U2.14, U3.7 (AIN3)
GND: C1.2, C2.2, C3.1, C4.1, C5.1, C6.1, C7.1, C8.1, D1.1 (K), J2.2, J3.2, MCU1.2 (GND), MCU1.14 (GND), MCU1.15 (GND), MCU1.23 (GND), MCU1.24 (GND), R14.2, R17.2, U1.11 (V-), U2.11 (V-), U3.3 (GND), U4.1 (ADDR), U4.3 (GND), U5.1 (GND), U6.3 (A)
unnamed: D1.2 (A), R11.1
unnamed: MCU1.22 (GPIO21/I2C_SDA), R10.1, U5.4 (SDA1)
unnamed: MCU1.21 (GPIO22/I2C_SCL), R9.1, U5.3 (SCL1)
unnamed: MCU1.4 (GPIO26/ADC19/DAC2), TP1.1
unnamed: U1.1, U1.2 (-), U4.7 (AIN3)
unnamed: U1.6 (-), U1.7, U4.6 (AIN2)
unnamed: U1.8, U1.9 (-), U4.5 (AIN1)
unnamed: U1.13 (-), U1.14, U4.4 (AIN0)
unnamed: R12.1, R13.1, R15.1, U2.3 (+), U6.1 (K)
unnamed: U2.6 (-), U2.7, U3.5 (AIN1)
unnamed: R16.2, R17.1, U2.10 (+)
unnamed: R15.2, R16.1, U2.12 (+)
unnamed: R7.1, U3.10 (SCL), U4.10 (SCL), U5.6 (SCL2)
unnamed: R8.1, U3.9 (SDA), U4.9 (SDA), U5.5 (SDA2)
unnamed: C3.2, R6.1, U5.7 (VREF2), U5.8 (EN)
unnamed: C4.2, MCU1.13 (3V3), R9.2, R10.2, U5.2 (VREF1)
unnamed: R13.2, R14.1, U6.2 (REF)

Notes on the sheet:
Expected 2.5 V output.
Overload LED

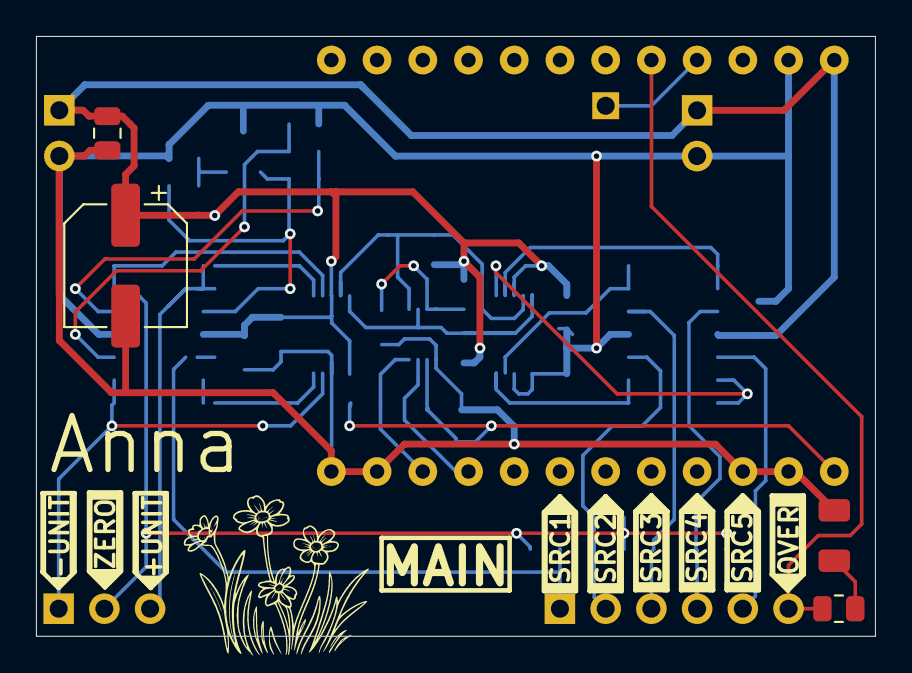
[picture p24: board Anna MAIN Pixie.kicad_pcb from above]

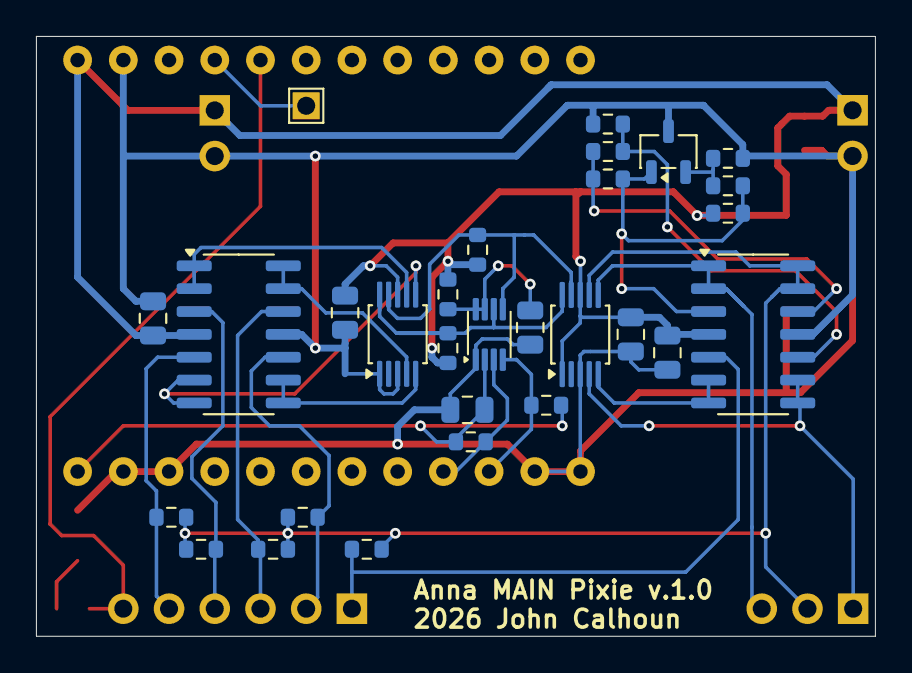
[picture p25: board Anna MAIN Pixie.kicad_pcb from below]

Board: 2 copper layers, 46.6 x 33.3 mm, 38 parts (33 on the bottom side), 28 nets.

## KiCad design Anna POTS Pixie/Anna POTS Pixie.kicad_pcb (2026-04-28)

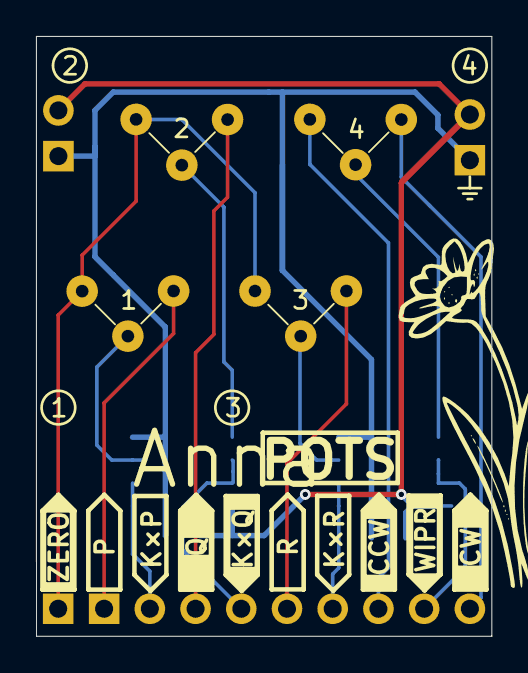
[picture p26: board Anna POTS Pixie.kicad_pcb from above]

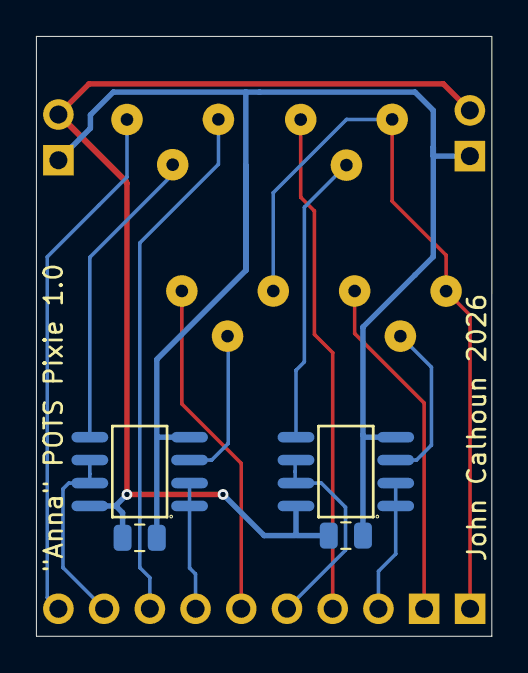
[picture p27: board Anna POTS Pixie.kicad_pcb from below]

Board: 2 copper layers, 25.3 x 33.3 mm, 12 parts (8 on the bottom side), 16 nets.

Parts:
1, 2, 3, 4: R_Potentiometer; Potentiometer_Blue_Trimpot_Universal
C1, C2: 0.1 µF; C_0805_2012Metric
J1: Conn_01x01_Pin; PinHeader_1x01_P2.54mm_Vertical
J2, J3: Conn_01x02_Pin; PinHeader_1x02_P2.54mm_Vertical
J4: Conn_01x09_Pin; PinHeader_1x09_P2.54mm_Vertical
U1, U2: MCP6002-xMC; SOIC-8_L4.9-W3.9-P1.27-LS6.0-BL

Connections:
GND: C1.2, C2.2, J2.1, J3.1, U1.4 (V-), U2.4 (V-)
unnamed: 1.1, 2.1, 3.1, J1.1
unnamed: C1.1, C2.1, J2.2, J3.2, U1.8 (V+), U2.8 (V+)
unnamed: 1.3, J4.1
unnamed: J4.2, U2.1, U2.2 (-)
unnamed: 2.3, J4.3
unnamed: J4.4, U2.6 (-), U2.7
unnamed: 3.3, J4.5
unnamed: J4.6, U1.1, U1.2 (-)
unnamed: 4.1, J4.7
unnamed: J4.8, U1.6 (-), U1.7
unnamed: 4.3, J4.9
unnamed: 3.2, U1.3 (+)
unnamed: 4.2, U1.5 (+)
unnamed: 1.2, U2.3 (+)
unnamed: 2.2, U2.5 (+)

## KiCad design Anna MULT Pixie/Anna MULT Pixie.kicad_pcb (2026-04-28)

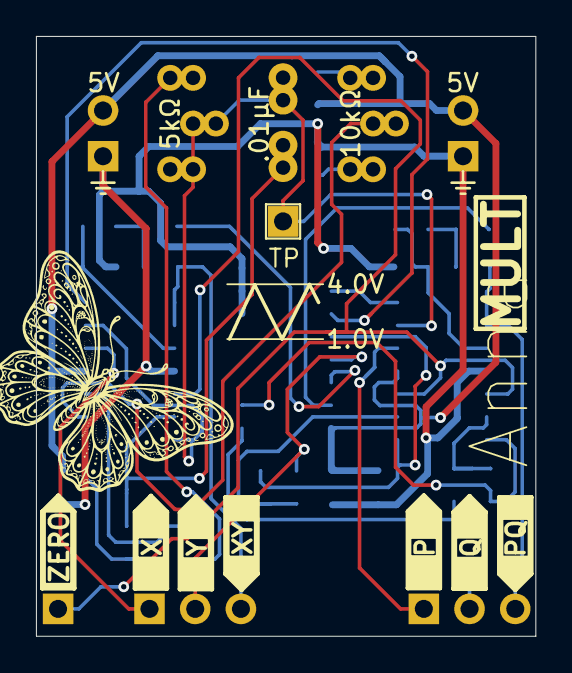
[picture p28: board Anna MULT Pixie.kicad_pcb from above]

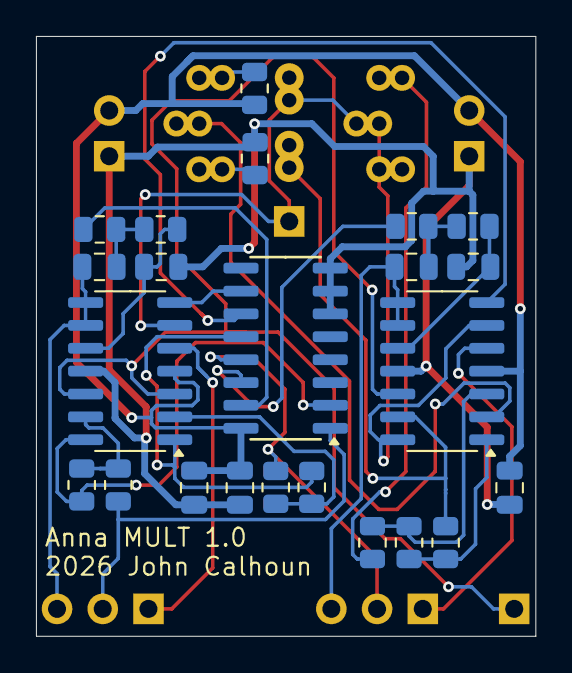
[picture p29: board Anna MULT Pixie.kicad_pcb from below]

Board: 2 copper layers, 27.7 x 33.3 mm, 32 parts (28 on the bottom side), 29 nets.

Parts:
5kΩ: 5 kΩ; Potentiometer_Bourns_3296W_Vertical
10kΩ: 10 kΩ; Potentiometer_Bourns_3296W_Vertical
.01µF: 0.01 µF; C_Rect_L7.0mm_W3.5mm_P2.50mm_P5.00mm
C2, C7: 0.033 µF; C_0805_2012Metric
C3, C4, C8: 0.1 µF; C_0805_2012Metric
C5, C6: 0.015 µF; C_0805_2012Metric
J1, J5: Conn_01x03_Pin; PinHeader_1x03_P2.54mm_Vertical
J2, J3: Conn_01x02_Pin; PinHeader_1x02_P2.54mm_Vertical
J4: Conn_01x01_Pin; PinHeader_1x01_P2.54mm_Vertical
R1, R3, R4, R5, R6, R7, R8, R9, R10, R11, R12, R13: 10 kΩ; R_0805_2012Metric
R2: 2.2 kΩ; R_0805_2012Metric
TP: TestPoint; TestPoint_THTPad_1.5x1.5mm_Drill0.7mm
U1, U2: MCP6004; SOIC-14_L8.7-W3.9-P1.27-LS6.0-BL
U3: CD4053B; SOIC-16_3.9x9.9mm_P1.27mm

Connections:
+5V: C3.2, C4.1, C8.1, J2.2, J3.2, R12.2, U1.4 (V+), U2.4 (V+), U3.16 (VDD)
/-Y1: R5.2, U2.1, U3.12 (A0)
/-Y2: R9.2, U2.14, U3.2 (B0)
GND: C3.1, C4.2, C5.2, C6.2, C8.2, J2.1, J3.1, R13.1, U1.11 (V-), U2.11 (V-), U3.6 (INH), U3.7 (VEE), U3.8 (VSS)
unnamed: C2.2, R6.1, R7.2
unnamed: C7.2, R10.2, R11.1
unnamed: R1.2, R3.1, U1.1
unnamed: 5kΩ.1, R2.2
unnamed: 10kΩ.1, R12.1
unnamed: 10kΩ.3, R13.2
unnamed: R1.1, R2.1, U1.3 (+)
unnamed: 10kΩ.2, U1.2 (-)
unnamed: 5kΩ.2, 5kΩ.3, .01µF.2, TP.1, U1.6 (-), U1.14, U2.6 (-)
unnamed: C6.1, R6.2, U1.10 (+)
unnamed: .01µF.1, R3.2, U1.13 (-)
unnamed: R4.2, R5.1, U2.2 (-)
unnamed: C5.1, R11.2, U2.10 (+)
unnamed: R8.2, R9.1, U2.13 (-)
unnamed: R7.1, U3.14 (A)
unnamed: R10.1, U3.15 (B)
unnamed: U1.7, U3.11 (S1)
unnamed: U2.7, U3.10 (S2)
X1: J1.1, U1.5 (+)
X1xY1: C2.1, J1.3, U1.8, U1.9 (-)
X2: J5.1, U2.5 (+)
X2xY2: C7.1, J5.3, U2.8, U2.9 (-)
Y1: J1.2, R4.1, U3.13 (A1)
Y2: J5.2, R8.1, U3.1 (B1)
ZERO: J4.1, U1.12 (+), U2.3 (+), U2.12 (+)

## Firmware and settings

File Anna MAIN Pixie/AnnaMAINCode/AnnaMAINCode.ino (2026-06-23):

// =============================================================================
//                                AnnaMAINPixie
// =============================================================================

#include <Adafruit_ADS1X15.h>
#include <Arduino.h>
#include <TFT_eSPI.h>
#include <WiFi.h>
#include <Wire.h>
#include "LunarLander.h"
#include "MassSpring.h"
#include "MeterUtils.h"
#include "RawDisplay.h"
#include "Scope.h"
#include "StripChart.h"
#include "SweepMeters.h"
#include "Utilities.h"
#include "VerticalMeters.h"


#define VERTICAL_METERINGMODE     0
#define SWEEP_METERINGMODE        1
#define STRIPCHART_METERINGMODE   2
#define SCOPE_METERINGMODE        3
#define MASSSPRING_METERINGMODE   4
#define LUNARLANDER_METERINGMODE  5
#define RAWDISPLAY_METERINGMODE   6
#define METERINGMODE_COUNT        7

#define SDA_PIN                   21    // For I2C communication with external ADCs. 
#define SCL_PIN                   22    // For I2C communication with external ADCs. 
#define OVERLOAD_OUT_PIN          25    // Set high if any source is over/under voltage.
#define EXP_DAC_PIN               26    // Unused.

#define DEFAULT_ALPHA             1.0f  // 1.0 —> no alpha (averaging).


const float CLIP_EPS = 1e-6;            // Avoid divide-by-zero

Adafruit_ADS1015 adsSourcesGND;         // ADS1x15 with address==GND
Adafruit_ADS1015 adsSources3V3;         // ADS1x15 with address==3V3

TFT_eSPI tft = TFT_eSPI ();
TFT_eSprite spriteBuffer = TFT_eSprite (&tft);

uint16_t displayWidth = 0;              // 240 on T-Display.
uint16_t displayHeight = 0;             // 135 on T-Display.

float alpha = DEFAULT_ALPHA;            // Each metering mode declares alpha.

MeterData meterData;                    // Struct containing data to be passed to the meters.
RawData rawData;                        // Struct containing raw values from DACs with alpha applied.
volatile int16_t adcResults[8] = {0};   // Array of raw values read from DACs.
portMUX_TYPE adcMux = portMUX_INITIALIZER_UNLOCKED;

int meterMode = SWEEP_METERINGMODE;
uint32_t loopCount = 0;
uint32_t nextBlink = 0;
bool blinkState = false;
bool countingDown = true;
unsigned long lastTime = 0;
int overlayMode = -1;
int overlayPosition = 0;
unsigned long overlayTime = 0;

// =================================================================== Functions
// ------------------------------------------------------------------- adcTask

void adcTask (void *parameter) {
  int16_t rawUnitNegOne;
  int16_t rawUnitZero;
  int16_t rawUnitOne;
  uint8_t loopCount = 0;

  // Runs on Core 0, continuously reading ADCs.

  while (true) {
    // Read reference voltages less frequently to save cycles.
    if (loopCount % 10 == 0) {
      rawUnitNegOne = adsSources3V3.readADC_SingleEnded (0);
      rawUnitZero = adsSources3V3.readADC_SingleEnded (3);
      rawUnitOne = adsSources3V3.readADC_SingleEnded (2);
    }

    // Always read dynamic ADCs.
    int16_t source1 = adsSources3V3.readADC_SingleEnded (1);
    int16_t source2 = adsSourcesGND.readADC_SingleEnded (1);  
    int16_t source3 = adsSourcesGND.readADC_SingleEnded (0);
    int16_t source4 = adsSourcesGND.readADC_SingleEnded (3);
    int16_t source5 = adsSourcesGND.readADC_SingleEnded (2);

    portENTER_CRITICAL (&adcMux);
    adcResults[0] = source1;
    adcResults[1] = source2;
    adcResults[2] = source3;
    adcResults[3] = source4;
    adcResults[4] = source5;
    adcResults[5] = rawUnitNegOne;
    adcResults[6] = rawUnitZero;
    adcResults[7] = rawUnitOne;
    portEXIT_CRITICAL (&adcMux);

    loopCount = loopCount + 1;
  }
}

// ------------------------------------------------------------------- computeMachineFromRaw

float computeMachineFromRaw (float raw) {
  float positiveRange = rawData.rawUnitOne - rawData.rawUnitZero;
  float negativeRange = rawData.rawUnitZero - rawData.rawUnitNegOne;

  // Protect against divide by zero; fallback to assuming full-scale (rawMin=0)
  if (positiveRange < CLIP_EPS)
    positiveRange = 1.0f;
  if (negativeRange < CLIP_EPS)
    negativeRange = rawData.rawUnitZero > 0.0 ? rawData.rawUnitZero : 1.0f;
  
  float m;
  if (raw >= rawData.rawUnitZero) {
    m = (raw - rawData.rawUnitZero) / positiveRange;    // 0..1
  } else {
    m = (raw - rawData.rawUnitZero) / negativeRange;    // -1..0
  }
  
  return m;
}

// Clear Output of Serial Monitor (Arduino IDE) before calling.
// When data is finished being sent, copy text from Serial Monitor and paste into plaintext 
// document (.ppm extension).
// Using magick (command-line tool): magick in_screenshot.ppm out_screenshot.png

void debug_dumpScreenAsPPM (TFT_eSprite &spr, int w, int h) {
    Serial.printf ("P3\n%d %d\n255\n", w, h);
    for (int y = 0; y < h; y++) {
        for (int x = 0; x < w; x++) {
            uint16_t c = spr.readPixel(x, y);  // RGB565
            uint8_t r = ((c >> 11) & 0x1F) << 3;
            uint8_t g = ((c >> 5)  & 0x3F) << 2;
            uint8_t b = ( c        & 0x1F) << 3;
            Serial.printf("%d %d %d ", r, g, b);
        }
        Serial.print('\n');
        delay(2);  // give Serial buffer time to drain
    }
}

// ------------------------------------------------------------------- assignMeterMode

void assignMeterMode (int newMode) {
  // Free up storage from all metering modes (will be a NOP for those already cleaned up).
  cleanupVerticalMeters ();
  cleanupSweepMeters ();
  cleanupStripChart ();
  cleanupScope ();
  cleanupMassSpring ();
  cleanupLunarLander ();
  cleanupRawDisplay ();

  // Clear buffer.
  spriteBuffer.fillSprite (TFT_BLACK);
  
  // Assign, init.
  meterMode = newMode;
  switch (meterMode) {
    case VERTICAL_METERINGMODE:
    alpha = prepareVerticalMeters (&tft);
    break;

    case SWEEP_METERINGMODE:
    alpha = prepareSweepMeters (&tft);
    break;
    
    case STRIPCHART_METERINGMODE:
    alpha = prepareStripChart (&tft);
    break;
    
    case SCOPE_METERINGMODE:
    alpha = prepareScope (&tft);
    break;
    
    case MASSSPRING_METERINGMODE:
    alpha = prepareMassSpring (&tft);
    break;

    case LUNARLANDER_METERINGMODE:
    alpha = prepareLunarLander (&tft);
    break;

    default:
    alpha = prepareRawDisplay (&tft);
    break;
  }
}

// ------------------------------------------------------------------- meteringModeSupportsDisablingInputs

bool meteringModeSupportsDisablingInputs (int mode) {
  return (mode == VERTICAL_METERINGMODE) || (mode == SWEEP_METERINGMODE) || (mode == STRIPCHART_METERINGMODE);
}

// ------------------------------------------------------------------- handleMetering

#define BLINK_INTERVAL    200

void handleMetering () {
  unsigned long now = millis ();
  if (now >= nextBlink) {
    blinkState = !blinkState;
    nextBlink = now + BLINK_INTERVAL;
    meterData.blinkState = blinkState;
  }
  
  // Assign to meter data.
  meterData.source1 = computeMachineFromRaw (rawData.source1);
  meterData.source2 = computeMachineFromRaw (rawData.source2);
  meterData.source3 = computeMachineFromRaw (rawData.source3);
  meterData.source4 = computeMachineFromRaw (rawData.source4);
  meterData.source5 = computeMachineFromRaw (rawData.source5);
  
  switch (meterMode) {
    case VERTICAL_METERINGMODE:
    runVerticalMeters (&meterData);
    break;

    case SWEEP_METERINGMODE:
    runSweepMeters (&meterData);
    break;
    
    case STRIPCHART_METERINGMODE:
    runStripChart (&meterData);
    break;

    case SCOPE_METERINGMODE:
    runScope (&meterData);
    break;

    case MASSSPRING_METERINGMODE:
    runMassSpring (&meterData);
    break;

    case LUNARLANDER_METERINGMODE:
    runLunarLander (&meterData);
    break;

    default:
    runRawDisplay (&meterData, &rawData);
    break;
  }

  if (bottomButtonPressed ()) {
    meterMode = meterMode + 1;
    if (meterMode >= METERINGMODE_COUNT) {
      meterMode = 0;  // Wrap around to beginning metering mode.
    }

    // Enable for grabbing screenshots.
    // debug_dumpScreenAsPPM (spriteBuffer, displayWidth, displayHeight);
    
    assignMeterMode (meterMode);
    
    overlayMode = 0;
    overlayPosition = displayHeight;
  }
}

char *_meteringModeDisplayName () {
  switch (meterMode) {
    case VERTICAL_METERINGMODE:
    return "Vertical Meters";
    break;

    case SWEEP_METERINGMODE:
    return "Sweep Meters";
    break;
    
    case STRIPCHART_METERINGMODE:
    return "Strip Chart";
    break;
    
    case SCOPE_METERINGMODE:
    return "XY Scope";
    break;

    case MASSSPRING_METERINGMODE:
    return "Spring + Mass";
    break;
    
    case LUNARLANDER_METERINGMODE:
    return "Lunar Lander";
    break;

    default:
    return "Raw Values";
    break;
  }
}

void handleOverlay (void) {
  if (overlayMode < 0) {
    return;
  }
  
  if (overlayMode == 0) {
    overlayPosition = overlayPosition - 1;
    if (overlayPosition <= displayHeight - 21) {
      overlayMode = 1;
      overlayTime = millis () + 1000;
    }
  } else if (overlayMode == 1) {
      if (millis () > overlayTime) {
        overlayMode = 2;
      }
  } else if (overlayMode == 2) {
    overlayPosition = overlayPosition + 1;
    if (overlayPosition > displayHeight) {
      overlayMode = -1;
      return;
    }
  }

  spriteBuffer.drawFastHLine (0, overlayPosition - 1, displayWidth, TFT_BLACK);
  spriteBuffer.fillRect (0, overlayPosition, displayWidth, 21, TFT_WHITE);
  spriteBuffer.fillRect (0, overlayPosition, displayWidth, 21, TFT_WHITE);

  spriteBuffer.setTextFont (1);
  spriteBuffer.setTextSize (2);
  spriteBuffer.setTextDatum (TC_DATUM);
  spriteBuffer.setTextColor (TFT_BLACK, TFT_WHITE);
  spriteBuffer.drawString (_meteringModeDisplayName (), displayWidth / 2, overlayPosition + 3);
}

// ------------------------------------------------------------------- testOverload

bool testOverload (float min, float max) {
  bool modeCanDisableInputs = meteringModeSupportsDisablingInputs (meterMode);
  
  // Handle under-over voltages.
  // Always test source1.
  if ((rawData.source1 < min) || (rawData.source1 > max)) {
    return true;
  }
  
  // Only test source2 if more than 1 input is enabled.
  if ((meterData.inputEnabledCount < 2) && (modeCanDisableInputs)) {
    goto done;
  }
  if ((rawData.source2 < min) || (rawData.source2 > max)) {
    return true;
  }

  // Only test source3 if more than 2 inputs are enabled.
  if ((meterData.inputEnabledCount < 3) && (modeCanDisableInputs)) {
    goto done;
  }
  if ((rawData.source3 < min) || (rawData.source3 > max)) {
    return true;
  }

  // Only test source4 if more than 3 inputs are enabled.
  if ((meterData.inputEnabledCount < 4) && (modeCanDisableInputs)) {
    goto done;
  }
  if ((rawData.source4 < min) || (rawData.source4 > max)) {
    return true;
  }
  
  // Only test source5 if more than 4 inputs are enabled.
  if ((meterData.inputEnabledCount < 5) && (modeCanDisableInputs)) {
    goto done;
  }
  if ((rawData.source5 < min) || (rawData.source5 > max)) {
    return true;
  }

done:

  return false;
}

// ------------------------------------------------------------------- fps

void fps () {
  unsigned long now = millis ();
  unsigned long delta = now - lastTime;

  if (delta > 0) {
    float fps = 1000.0f / delta;
    Serial.println (fps);
  }

  lastTime = now;
}

// ------------------------------------------------------------------- handleInputEnabling

void handleInputEnabling () {
  // Store away a button press.
  meterData.buttonToggle = topButtonPressed ();
  if (meterData.buttonToggle && meteringModeSupportsDisablingInputs (meterMode)) {
    if (meterData.inputEnabledCount >= 5) {
      countingDown = true;
    } else if (meterData.inputEnabledCount <= 1) {
      countingDown = false;
    }
    if (countingDown) {
      meterData.inputEnabledCount = meterData.inputEnabledCount - 1;
    } else {
      meterData.inputEnabledCount = meterData.inputEnabledCount + 1;
    }
  }
}

// ------------------------------------------------------------------- loop

void loop () {
  // Read shared results safely
  int16_t adcSnapshot[8];
  portENTER_CRITICAL (&adcMux);
  memcpy (adcSnapshot, (void *) adcResults, sizeof (adcSnapshot));
  portEXIT_CRITICAL (&adcMux);

  // Assign and alpha.
  rawData.source1 = (alpha * (float) adcSnapshot[0]) + ((1.0 - alpha) * rawData.source1);
  rawData.source2 = (alpha * (float) adcSnapshot[1]) + ((1.0 - alpha) * rawData.source2);
  rawData.source3 = (alpha * (float) adcSnapshot[2]) + ((1.0 - alpha) * rawData.source3);
  rawData.source4 = (alpha * (float) adcSnapshot[3]) + ((1.0 - alpha) * rawData.source4);
  rawData.source5 = (alpha * (float) adcSnapshot[4]) + ((1.0 - alpha) * rawData.source5);
  rawData.rawUnitNegOne = (alpha * (float) adcSnapshot[5]) + ((1.0 - alpha) * rawData.rawUnitNegOne);
  rawData.rawUnitZero = (alpha * (float) adcSnapshot[6]) + ((1.0 - alpha) * rawData.rawUnitZero);
  rawData.rawUnitOne = (alpha * (float) adcSnapshot[7]) + ((1.0 - alpha) * rawData.rawUnitOne);
  
  // Handle overload (voltages getting too close to the rails).
  bool modeCanDisableInputs = meteringModeSupportsDisablingInputs (meterMode);
  bool overload = false;
  float minVoltage= rawData.rawUnitNegOne;
  float maxVoltage= rawData.rawUnitOne;

  meterData.source1Overloaded = false;
  meterData.source2Overloaded = false;
  meterData.source3Overloaded = false;
  meterData.source4Overloaded = false;
  meterData.source5Overloaded = false;

  // Always test input 1.
  if ((rawData.source1 < minVoltage) || (rawData.source1 > maxVoltage)) {
    meterData.source1Overloaded = true;
    overload = true;
  }

  // Only test source2 if more than 1 input is enabled.
  if ((meterData.inputEnabledCount < 2) && (modeCanDisableInputs)) {
    goto done;
  } else if ((rawData.source2 < minVoltage) || (rawData.source2 > maxVoltage)) {
    meterData.source2Overloaded = true;
    overload = true;
  }

  // Only test source3 if more than 2 inputs are enabled.
  if ((meterData.inputEnabledCount < 3) && (modeCanDisableInputs)) {
    goto done;
  } else if ((rawData.source3 < minVoltage) || (rawData.source3 > maxVoltage)) {
    meterData.source3Overloaded = true;
    overload = true;
  }
  
  // Only test source4 if more than 3 inputs are enabled.
  if ((meterData.inputEnabledCount < 4) && (modeCanDisableInputs)) {
    goto done;
  } else if ((rawData.source4 < minVoltage) || (rawData.source4 > maxVoltage)) {
    meterData.source4Overloaded = true;
    overload = true;
  }

  if ((meterData.inputEnabledCount < 5) && (modeCanDisableInputs)) {
    goto done;
  } else if ((rawData.source5 < minVoltage) || (rawData.source5 > maxVoltage)) {
    meterData.source5Overloaded = true;
    overload = true;
  }

done:

  digitalWrite (OVERLOAD_OUT_PIN, overload ? HIGH : LOW);
  
  // Rendering.
  // Display the data.
  handleMetering ();
  handleOverlay ();
  spriteBuffer.pushSprite (0, 0);

  // Test for the top button pressed.
  handleInputEnabling ();

  // Bump loop counter.
  loopCount = loopCount + 1;
  
  // fps();
}

// ------------------------------------------------------------------- setup

void setup() {
  // Kill Wi-Fi.
  WiFi.mode (WIFI_OFF);
  WiFi.disconnect (true);

  // Set up serial.
  Serial.begin (115200);  // Common baud rate for ESP32
  while (!Serial) {
      ; // wait for serial port to connect. Needed for native USB
  }

  // Init TFT display.
  tft.init ();
  tft.setRotation (1);
  tft.fillScreen (TFT_BLACK);
  displayWidth = tft.width ();
  displayHeight = tft.height ();
  
  // Set up I2C.
  Wire.begin (SDA_PIN, SCL_PIN);
  Wire.setClock (100000);
  
  if (!adsSourcesGND.begin (ADS1X15_ADDRESS)) { // ADS1X15_ADDRESS == GND
    Serial.println ("Failed to initialize meters ADS.");
    while (1);
  }
  
  // Set gain so full-scale range.
  adsSourcesGND.setGain (GAIN_ONE);
  adsSourcesGND.setDataRate (RATE_ADS1015_3300SPS);  // ADS1015: RATE_ADS1015_3300SPS, ADS1115: RATE_ADS1115_860SPS
  
  if (!adsSources3V3.begin (ADS1X15_ADDRESS + 1)) {    // ADS1X15_ADDRESS + 1 == 3V3
    Serial.println ("Failed to initialize sources ADS.");
    while (1);
  }

  // Set gain so full-scale range.
  adsSources3V3.setGain (GAIN_ONE);
  adsSources3V3.setDataRate (RATE_ADS1015_3300SPS);  // ADS1015: RATE_ADS1015_3300SPS, ADS1115: RATE_ADS1115_860SPS
  
  // Pin adcTask to Core 0, loop() runs on Core 1
  xTaskCreatePinnedToCore (adcTask, "ADCTask", 2048, NULL, 1, NULL, 0);
  
  // Set up overload and experimental DAC output.
  pinMode (OVERLOAD_OUT_PIN, OUTPUT);
  // pinMode (EXP_DAC_PIN, OUTPUT);

  // Call utiltities to set up the button inputs (build into the T-Display).
  initUtilities ();

  // Create full-screen buffer (sprite).
  spriteBuffer.setColorDepth (16);
  spriteBuffer.setSwapBytes (false);
  spriteBuffer.createSprite (displayWidth, displayHeight);

  // Assign to meter data.
  meterData.buffer = &spriteBuffer;
  meterData.displayWidth = displayWidth;
  meterData.displayHeight = displayHeight;
  meterData.inputEnabledCount = 5;
  
  assignMeterMode (VERTICAL_METERINGMODE);

  Serial.println ("setup() COMPLETE!");
}

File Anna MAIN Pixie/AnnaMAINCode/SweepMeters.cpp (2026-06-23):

// =============================================================================
//                               SweepMeters.cpp
// =============================================================================

#include <Arduino.h>
#include "SweepMeters.h"
#include "Utilities.h"


#define SWEEPMETER_WIDTH    240
#define SWEEP_ORIGIN_Y      160

#define NEEDLE_END          148.0
#define NEEDLE_START        64.0
#define NEEDLE_WIDTH        3.0

#define SWEEPMETER_LABEL_X1 107 - 80  // 107 = (screenWidth / 2) - (LABEL_WIDTH / 2)
#define SWEEPMETER_LABEL_X2 107 - 40
#define SWEEPMETER_LABEL_X3 107 - 0
#define SWEEPMETER_LABEL_X4 107 + 40
#define SWEEPMETER_LABEL_X5 107 + 80

#define SWEEPMETER_LABEL_Y  106

#define SWEEPMETER_ALPHA     0.50f


TFT_eSprite *sweepMeterSprite = nullptr;

TFT_eSprite *sweepLabel1Sprite = nullptr;
TFT_eSprite *sweepLabel2Sprite = nullptr;
TFT_eSprite *sweepLabel3Sprite = nullptr;
TFT_eSprite *sweepLabel4Sprite = nullptr;
TFT_eSprite *sweepLabel5Sprite = nullptr;

TFT_eSprite *sweepLabel1OverSprite = nullptr;
TFT_eSprite *sweepLabel2OverSprite = nullptr;
TFT_eSprite *sweepLabel3OverSprite = nullptr;
TFT_eSprite *sweepLabel4OverSprite = nullptr;
TFT_eSprite *sweepLabel5OverSprite = nullptr;


// =================================================================== Functions
// ------------------------------------------------------------------- machineValueToAngle

#define SWEEPMETER_MAXANGLE 50.0f

// Maps value of -1.0 to +1.0 to angle of -135° to -45°

float machineValueToAngle (float value) {
  float angle = (value * 45.0);
  if (angle < -SWEEPMETER_MAXANGLE) {
    angle = -SWEEPMETER_MAXANGLE;
  } else if (angle > SWEEPMETER_MAXANGLE) {
    angle = SWEEPMETER_MAXANGLE;
  }
  
  // Linear interpolation.
  return -90 + angle;
}

// ------------------------------------------------------------------- drawNeedle

void drawNeedle (TFT_eSprite *buffer, uint16_t meterWidth, float value, uint16_t color) {
  float angleDeg = machineValueToAngle (value);
  float angleRad = angleDeg * (PI / 180.0);
  
  // Direction vector.
  float dx = cos (angleRad);
  float dy = sin (angleRad);

  // Perpendicular vector for width.
  float nx = -dy;
  float ny = dx;

  // Compute 4 corners of the needle polygon.
  float halfW = NEEDLE_WIDTH / 2.0;
  float x0 = (meterWidth / 2) + dx * NEEDLE_START + nx * halfW;  // base left
  float y0 = SWEEP_ORIGIN_Y + dy * NEEDLE_START + ny * halfW;
  float x1 = (meterWidth / 2) + dx * NEEDLE_START - nx * halfW;  // base right
  float y1 = SWEEP_ORIGIN_Y + dy * NEEDLE_START - ny * halfW;
  float x2 = (meterWidth / 2) + dx * NEEDLE_END + nx * halfW;  // tip left
  float y2 = SWEEP_ORIGIN_Y + dy * NEEDLE_END + ny * halfW;
  float x3 = (meterWidth / 2) + dx * NEEDLE_END - nx * halfW;  // tip right
  float y3 = SWEEP_ORIGIN_Y + dy * NEEDLE_END - ny * halfW;
  
  // Draw the two triangles
  buffer->fillTriangle (x0 + 1, y0, x1 + 1, y1, x2 + 1, y2, color);
  buffer->fillTriangle (x1 + 1, y1, x2 + 1, y2, x3 + 1, y3, color);
}

// ------------------------------------------------------------------- runSweepMeters

void runSweepMeters (struct MeterData *data) {
  sweepMeterSprite->pushToSprite (data->buffer, 0, 0);

  // Draw needles.
  if (data->inputEnabledCount >= 5) {
    drawNeedle (data->buffer, data->displayWidth, data->source5, METER_LABEL_COLOR_5);
  }
  if (data->inputEnabledCount >= 4) {
    drawNeedle (data->buffer, data->displayWidth, data->source4, METER_LABEL_COLOR_4);
  }
  if (data->inputEnabledCount >= 3) {
    drawNeedle (data->buffer, data->displayWidth, data->source3, METER_LABEL_COLOR_3);
  }
  if (data->inputEnabledCount >= 2) {
    drawNeedle (data->buffer, data->displayWidth, data->source2, METER_LABEL_COLOR_2);
  }
  drawNeedle (data->buffer, data->displayWidth, data->source1, METER_LABEL_COLOR_1);
  
  // Draw labels last.
  if (data->blinkState && data->source1Overloaded) {
    sweepLabel1OverSprite->pushToSprite (data->buffer, SWEEPMETER_LABEL_X1, SWEEPMETER_LABEL_Y, TFT_TRANSPARENT);
  } else {
    sweepLabel1Sprite->pushToSprite (data->buffer, SWEEPMETER_LABEL_X1, SWEEPMETER_LABEL_Y, TFT_TRANSPARENT);
  }
  if (data->inputEnabledCount < 2) {
    goto done;
  }
  
  if (data->blinkState && data->source2Overloaded) {
    sweepLabel2OverSprite->pushToSprite (data->buffer, SWEEPMETER_LABEL_X2, SWEEPMETER_LABEL_Y, TFT_TRANSPARENT);
  } else {
    sweepLabel2Sprite->pushToSprite (data->buffer, SWEEPMETER_LABEL_X2, SWEEPMETER_LABEL_Y, TFT_TRANSPARENT);
  }
  if (data->inputEnabledCount < 3) {
    goto done;
  }

  if (data->blinkState && data->source3Overloaded) {
    sweepLabel3OverSprite->pushToSprite (data->buffer, SWEEPMETER_LABEL_X3, SWEEPMETER_LABEL_Y, TFT_TRANSPARENT);
  } else {
    sweepLabel3Sprite->pushToSprite (data->buffer, SWEEPMETER_LABEL_X3, SWEEPMETER_LABEL_Y, TFT_TRANSPARENT);
  }
  if (data->inputEnabledCount < 4) {
    goto done;
  }

  if (data->blinkState && data->source4Overloaded) {
    sweepLabel4OverSprite->pushToSprite (data->buffer, SWEEPMETER_LABEL_X4, SWEEPMETER_LABEL_Y, TFT_TRANSPARENT);
  } else {
    sweepLabel4Sprite->pushToSprite (data->buffer, SWEEPMETER_LABEL_X4, SWEEPMETER_LABEL_Y, TFT_TRANSPARENT);
  }
  if (data->inputEnabledCount < 5) {
    goto done;
  }
  
  if (data->blinkState && data->source5Overloaded) {
    sweepLabel5OverSprite->pushToSprite (data->buffer, SWEEPMETER_LABEL_X5, SWEEPMETER_LABEL_Y, TFT_TRANSPARENT);
  } else {
    sweepLabel5Sprite->pushToSprite (data->buffer, SWEEPMETER_LABEL_X5, SWEEPMETER_LABEL_Y, TFT_TRANSPARENT);
  }
  
done:
  
  return;
}

// ------------------------------------------------------------------- createSweepMeterSprite

TFT_eSprite *createSweepMeterSprite (TFT_eSPI *tft) {
  TFT_eSprite *sprite = new TFT_eSprite (tft);
  uint16_t width = tft->width ();
  uint16_t height = tft->height ();

  // Create sprite.
  sprite = new TFT_eSprite (tft);
  sprite->setColorDepth (16);
  sprite->createSprite (width, height);

  // Background of sprite and white panel arc.
  sprite->fillSprite (TFT_DARKGREY);
  sprite->drawSmoothArc (width / 2, SWEEP_ORIGIN_Y, NEEDLE_END, NEEDLE_END * 2.0 / 3.0, 135, 225, TFT_WHITE, TFT_LIGHTGREY, false);

  // Tick marks.
  for (int i = -25; i <= 25; i++) {
    float angleRad = (((float) i * 1.8f) + 90.0) * (PI / 180.0);
    float dx = cos (angleRad);
    float dy = sin (angleRad);

    float length = (i % 5 == 0) ? 16.0 : 8.0;
    float x0 = (width / 2) + (dx * NEEDLE_END);
    float y0 = SWEEP_ORIGIN_Y - (dy * NEEDLE_END);
    float x1 = (width / 2) + (dx * (NEEDLE_END - length));
    float y1 = SWEEP_ORIGIN_Y - (dy * (NEEDLE_END - length));
    
    sprite->drawWideLine (x0, y0, x1, y1, 1.0, TFT_DARKGREY, TFT_WHITE);
  }

  return sprite;
}

// ------------------------------------------------------------------- prepareSweepMeters
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

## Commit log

2026-04-28 Add initial release of the Anna MULT Pixie.
    [Anna MULT Pixie.kicad_pcb, Anna MULT Pixie.kicad_sch]
2026-04-28 Added the first release of the ADD Pixie (PCB).
    [Anna POTS Pixie.kicad_pcb, Anna POTS Pixie.kicad_sch]
2026-04-29 Pulling in the Arduino sources for the MAIN module.
2026-04-29 Adding ADD and MAIN modules (PCBs, schamtics).
    [Anna ADD Pixie.kicad_pcb, Anna ADD Pixie.kicad_sch, Anna MAIN Pixie.kicad_pcb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]
2026-06-07 Added INT module. Also updated ADD module with larger SJ holes.
    [Anna ADD Pixie.kicad_pcb, Anna INT Pixie.kicad_pcb, Anna INT Pixie.kicad_sch]
2026-06-08 Add schematic.
2026-06-08 Added schematics and READMEs.
2026-07-23 Fix base voltage notation in README.md
    Corrected formatting of the base voltage notation in the triangle wave section.
